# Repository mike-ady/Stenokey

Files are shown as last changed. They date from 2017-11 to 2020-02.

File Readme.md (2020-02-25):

# Stenokey

Stenographic keyboard

Stenokey is an open source do it yourself stenographic keyboard project.  It is aimed 
at makers with some electronics experience (soldering) and who own a 3D printer 
or who have a friend with a 3D printer.

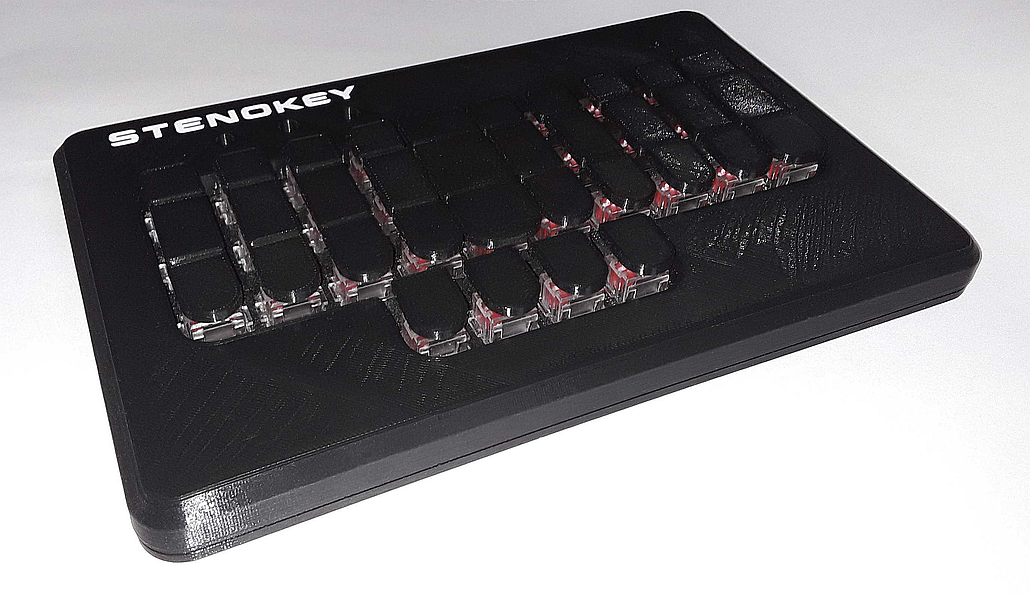
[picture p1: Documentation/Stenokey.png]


Stenokey connects to any desktop or laptop PC that has a USB port.  It is meant 
to work with the Open Steno Project's Plover software, which runs on Linux, Mac and 
Windows.

This project consists of four main parts:

- The OpenSCAD source code for all of the 3D printed plastic parts is in the main 
directory.  Printer ready .STL files for the key tops are in the Key\_Print\_Files 
directory.  The .STL files for the case are in the Case\_Print\_Files directory.  

- The bill of materials (BOM) for populating the circuit board is in the main 
directory.  The PCB design files are in the PCB directory.

- The Arduino based firmware is in the Firmware directory.

- Documentation for the project, including build instructions, programming and testing 
instructions and a user manual are all in the Documentation Directory.

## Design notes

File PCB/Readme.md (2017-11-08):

# Stenokey PCB Readme

Copyright © 2017, Mike Ady  
This file is part of the open source Stenokey project.  
This file is licensed under the Creative Commons Attribution-ShareAlike license.

## Directory Listing

- Gerbers -- This directory holds the files that are required to have circuit boards made.

- Stenokey.pretty -- This directory is the footprint library for the Stenokey project.

- Stenokey.kicad_pcb -- This is the circuit board layout file.

- Stenokey.kicad_wks -- This is the title block and frame layout file.

- Stenokey.lib -- This is the schematic library for the Stenokey project.

- Stenokey.pro -- This is the KiCAD project file.

- StenoKey.sch -- This is the schematic file.

- StenoKeyLogo.kicad_wks -- This is the Stenokey logo in KiCAD format.

The remaining files and directories were program generated.

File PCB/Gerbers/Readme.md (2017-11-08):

# Stenokey Gerbers Readme

Copyright © 2017, Mike Ady  
This file is part of the open source Stenokey project.  
This file is licensed under the Creative Commons Attribution-ShareAlike license.

## Directory Listing

Back.gvp -- This is a Gerbv project file which displays the back of the Stenokey PCB.

Front.gvp -- This is a Gerbv project file which displays the front of the Stenokey PCB.

names.bat -- Windows batch file to rename Gerber files output by KiCAD for submission to SeeedStudio.

StenoKey.GBL -- Bottom copper layer Gerber.

StenoKey.GBO -- Bottom silkscreen layer Gerber.

StenoKey.GBS -- Bottom solder mask layer Gerber.

StenoKey.GML -- Board outline layer Gerber.

StenoKey.GTL -- Top copper layer Gerber.

StenoKey.GTO -- Top silkscreen layer Gerber.

StenoKey.GTS -- Top solder mask layer Gerber.

StenoKey.TXT -- Drill file.

StenoKey.zip -- Archive submitted to SeeedStudio.

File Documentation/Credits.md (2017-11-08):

# Credits

Copyright © 2017, Mike Ady  
This file is part of the open source Stenokey project.  
This file is licensed under the Creative Commons Attribution-ShareAlike license.

# 3D Models

- KMR2 switch model was downloaded from CKSwitches.com.  
- M3 screw model was downloaded from TracePartsOnline.com.  
- Matias key switch model was downloaded from Matias.ca.  
- USB Mini-B model was downloaded from TracePartsOnline.com.  

These models were used generate a full 3D model of the Stenokey to aid in the design of the Stenokey case.

# Fonts (not included)

- Criovision font, by Criovision Agency was downloaded from dafont.com.  The Criovision font was used for the Stenokey logo.

# Tools (not included)

- Arduino IDE -- Arduino programming environment (open source).  The Arduino IDE is used to program the Teensy 2.0.  It was also used to edit and test the Stenokey firmware.  
- DraftSight -- 2D drafting program (free).  DraftSight was used to draw the key and case outlines for use in OpenSCAD.   
- FreeCAD -- 3D drawing program (open source).  FreeCAD was used to view and troubleshoot several .STL files and some of the Stenokey OpenSCAD code.  It was also used to convert files in other 3D formats to .STL format for use with OpenSCAD.  
- FreeRouting -- PCB Auto-routing program (open source).  FreeRouting was used to route the Stenokey PCB.
- Gerbv -- Gerber viewer (open source).  Gerbv (not Gerbview) was used view and verify the Stenokey PCB design.  
- Git -- Revision control system (open source).  Git provides version control.  
- Inkscape -- 2D graphic design program (open source).  Inkscape was used to draw the Stenokey logo.  
- KiCAD -- printed circuit board design software (open source).  KiCAD was used to design the Stenokey PCB.  
- MarkDownPad -- markdown editor and viewer (free -- Windows only).  MarkdownPad was used to format many of the Stenokey documents.  
- Netfabb -- 3D printer design software (free version).  Netfabb was used to obtain measurements from .STL files and to fix errors in .STL files.  
- Plover -- Stenographic translation program (open source).  Plover was used to troubleshoot the Stenokey firmware.  
- OpenOffice -- office utilities (open source).  Open office Calc was used for the Stenokey bill of materials (BOM). 
- OpenSCAD -- 3D drawing program (open source).  OpenSCAD was used to draw all of the Stenokey 3D printed parts.  
- SVG2MOD -- graphic conversion program for KiCAD (open source).  SVG2MOD was used to convert the Stenokey logo from SVG format to a KiCAD module (footprint).  The KiCAD module was hand edited to convert it to .kicad_wks format. 
- TeensyDuino -- Arduino compatible library and utilities (free).  The TeensyDuino libraries are used in the Stenokey firmware.  The Teensy utility is used to program the Teensy 2.0 module.  

# Documents (not included)

- Stenosaurus Keyboard Design was downloaded from stenosaurus.blogspot.ca.  The Stenokey key shapes and general board layout were essentially copied from the Stenosaurus project.
- Matais key switch prints were downloaded from matias.ca.  The prints were used to obtain key switch dimensions.

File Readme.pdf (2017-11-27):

# Stenokey

Stenographic keyboard

Stenokey is an open source do it yourself stenographic keyboard project. It is aimed at makers with some electronics experience (soldering) and who own a 3D printer or who have a friend with a 3D printer.

This project is not quite ready yet! The key tops and circuit board have been tested and are working. Here is a picture of the prototype:

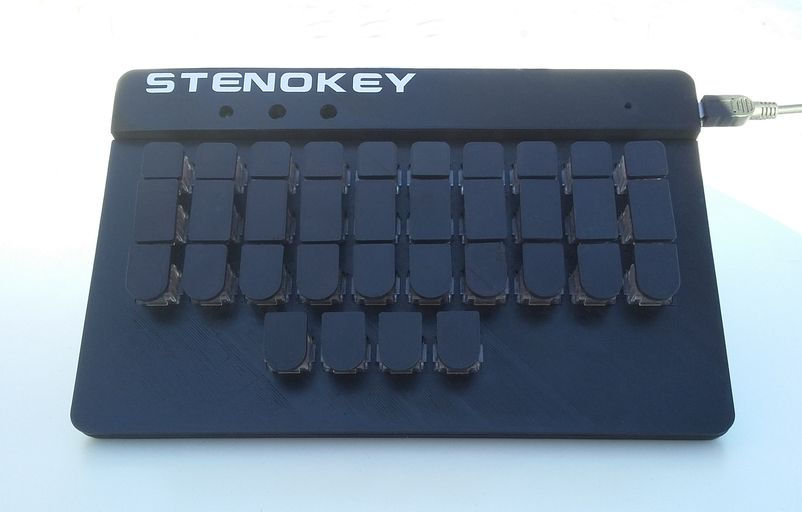
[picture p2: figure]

A clam shell case has been designed but it has not been printed or tested yet:

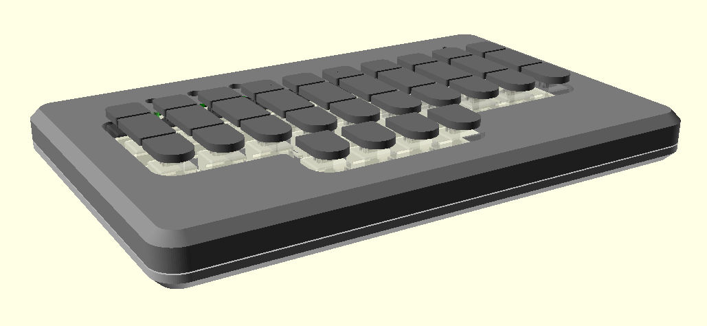
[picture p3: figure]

Stenokey connects to any desktop or laptop PC that has a USB port. It is meant to work with the Open Steno Project's Plover software, which runs on Linux, Mac and Windows.

This project consists of four main parts:

The OpenSCAD source code for all of the 3D printed plastic parts is in the main directory. Printer ready .STL files for the key tops are in the Key_Print_Files directory. The .STL files for the case are in the Case_Print_Files directory.

The bill of materials (BOM) for populating the circuit board is in the main directory. The PCB design files are in the PCB directory.

The Arduino based firmware is in the Firmware directory.

Documentation for the project, including build instructions, programming and testing instructions and a user manual are all in the Documentation Directory.

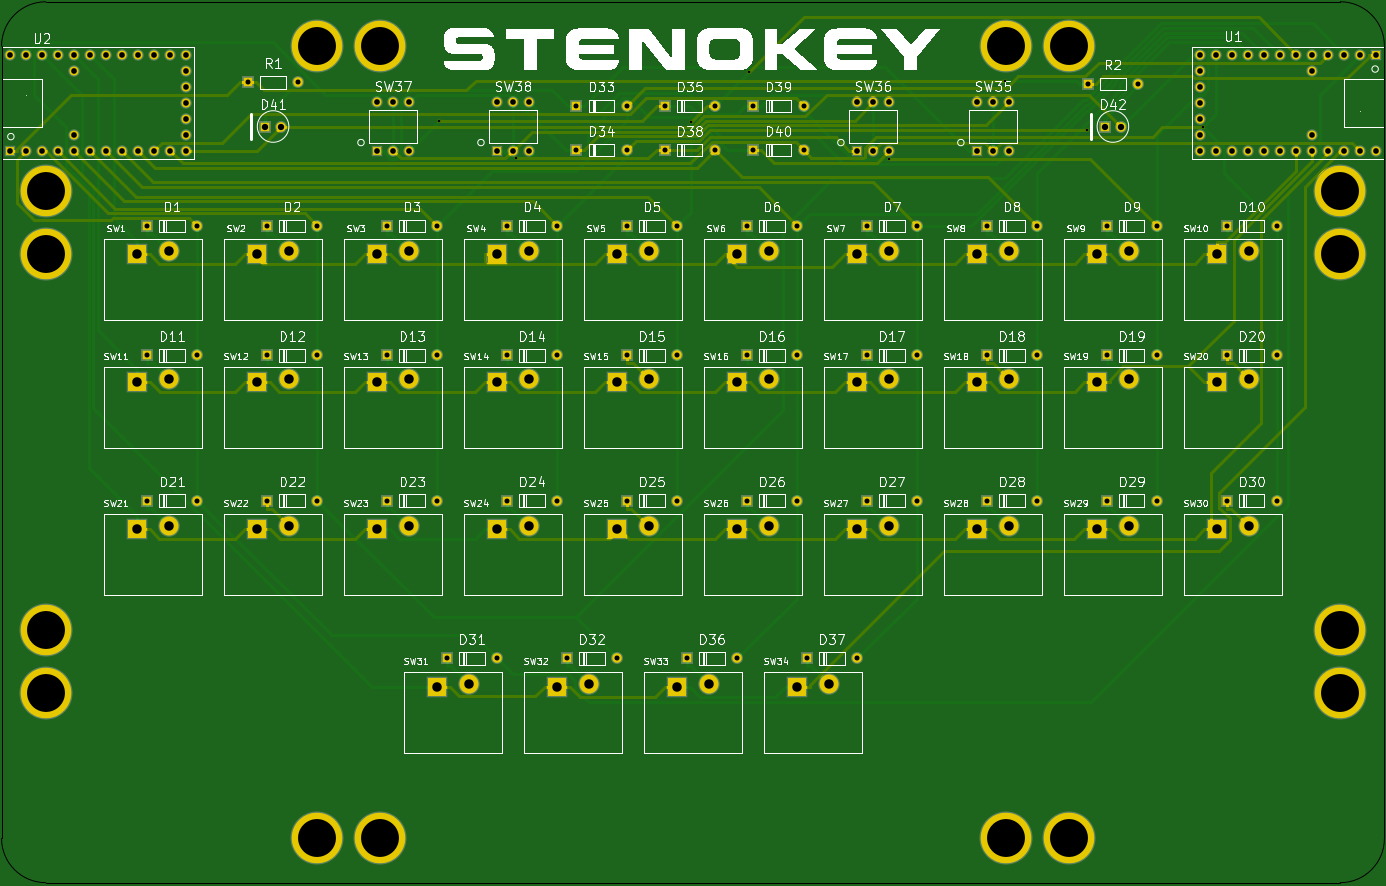
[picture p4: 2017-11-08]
Documentation/PCB_Front.png

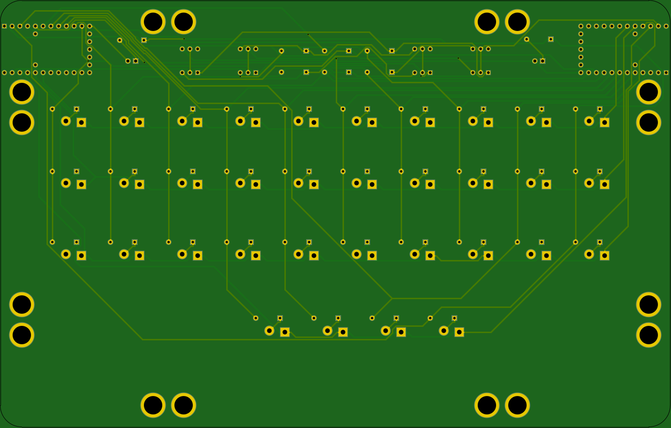
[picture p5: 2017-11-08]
Documentation/PCB_Back.png

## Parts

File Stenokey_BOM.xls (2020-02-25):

Stenokey Bill of Materials |  |  |  |  |  | Price | Price
 |  |  |  |  |  | Break | Break
Ref | Qty | Part Number | Manufacturer | Vendor Part Number | Vendor | Price | Qty | Extended Price | Description | Alternate Vendors
D1-D40 | 40 | 1N4148-T | Rectron | 583-1N4148-T | Mouser | $0.50 | 25 | $0.80 | Small Signal Diode | Digikey, Allied Electronics
D41 | 1 | LTL-307GLC | Liteon | 859-LTL-307GLC | Mouser | $0.10 | 1 | $0.10 | LED, 5 mm Dome, Green, 3 mcd | Digikey, Arrow Electronics
R1 | 1 | 299-510-RC | Xicon | 299-510-RC | Mouser | $0.15 | 10 | $0.01 | Resistor, 510R W125 | Digikey
SW1-SW34 | 34 |  | Matias |  | Matias | $50.00 | 200 | $8.50 | Key Switches, Quiet-Linear | Open Steno Project (Crowd Supply)
SW35-SW36 | 2 | 220ADA16 | CTS | 774-220ADA16 | Mouser | $1.98 | 1 | $3.96 | Rotary Switch, 16 Pos, DIP | Digikey, Arrow Electronics
U1 | 1 | Teensy 2.0 | PJRC | 199 | Adafruit | $15.95 | 1 | $15.95 | Teensy 2.0, with Header Pins | Mouser
 | 1 | N/A | Seeed Studio | N/A | Seeed Studio | $63.15 | 5 | $12.63 | Circuit Board, 1.6 mm | Itead, Osh Park
 | 1 | 88732-8610 | Molex | 538-88732-8610 | Mouser | $2.65 | 1 | $2.65 | Mini B to A USB Cable, 1 m | Digikey
 | 8 | N/A | N/A | 94180A333 | McMaster-Carr | $15.38 | 100 | $1.23 | M3 Heat Set Inserts, Tapered, Long | MakerTech Store
 | 8 | N/A | N/A | 92005A122 | McMaster-Carr | $2.72 | 100 | $0.22 | M3x12 mm Pan Head Screw | Most Hardware Stores
 |  |  |  |  |  | Total |  | $46.05
Component Substitution:
- Small signal diodes -- These are also available from various other manufacturers. Any 1N4148-T diode can be substituted.
- LED -- Note the specified brightness; many LED's are far too bright.
- 510 ohm, 1/8 watt resistor -- This is also available from varous other manufacturers.
- A resistor valued 470 ohms or higher can be substituted, though higher values will reduce the brightness of the LED.
- A 1/4 watt resistor can be substituted, though it's a tight fit.
Copyright © 2017, Mike Ady
This file is part of the open source Stenokey project.
This file is licensed under the GNU GPL V3.0.

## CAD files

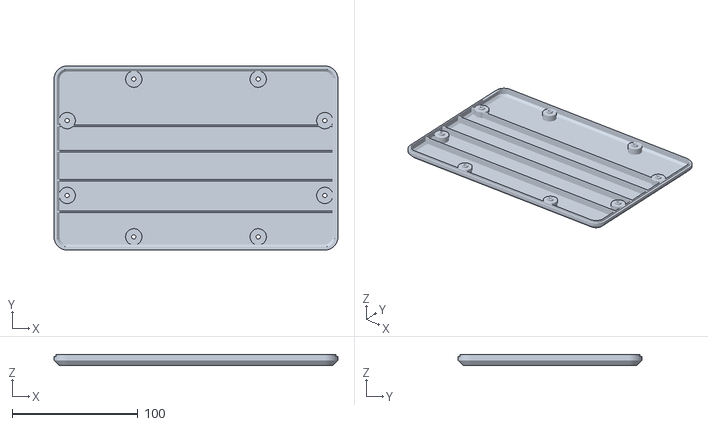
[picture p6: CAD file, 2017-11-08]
Case_Print_Files/BaseUSBLeft.stl
226.0 x 146.5 x 8.60

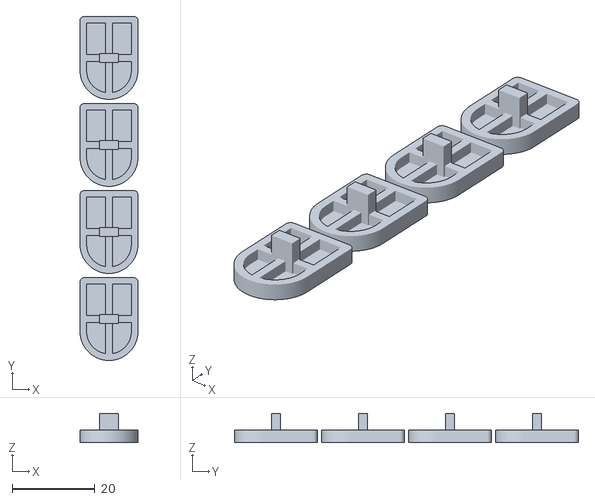
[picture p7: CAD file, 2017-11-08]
Key_Print_Files/Vowels.stl
14.0 x 83.0 x 7.00

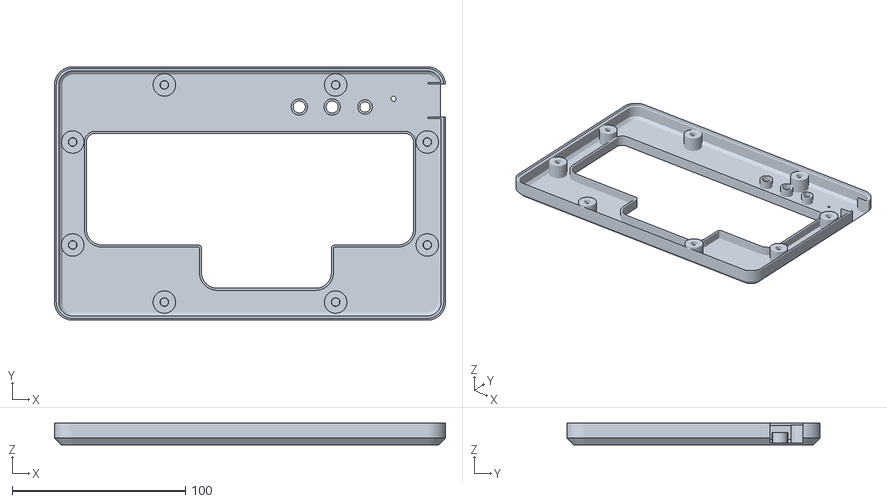
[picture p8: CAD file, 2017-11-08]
Case_Print_Files/TopIntLeftUSBLeft.stl
226.0 x 146.5 x 12.7

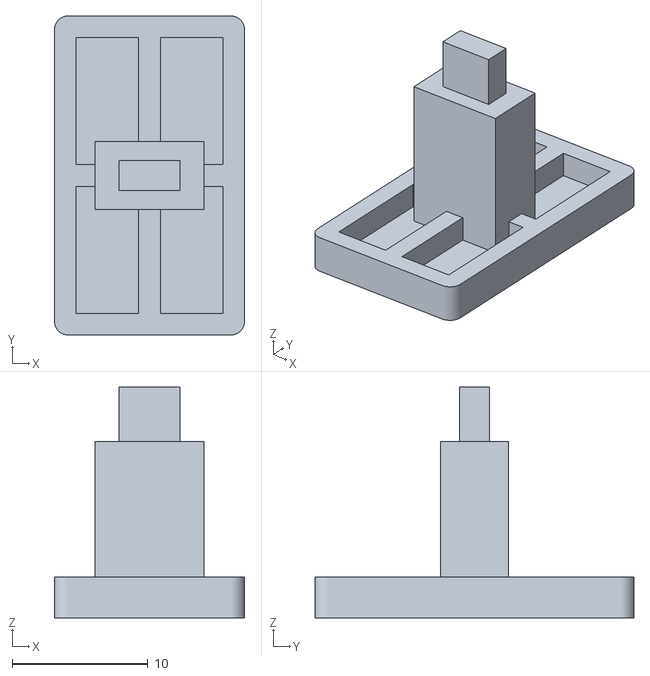
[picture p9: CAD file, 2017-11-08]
Key_Print_Files/KeyMiddleNarrowExtended.stl
14.0 x 23.5 x 17.0

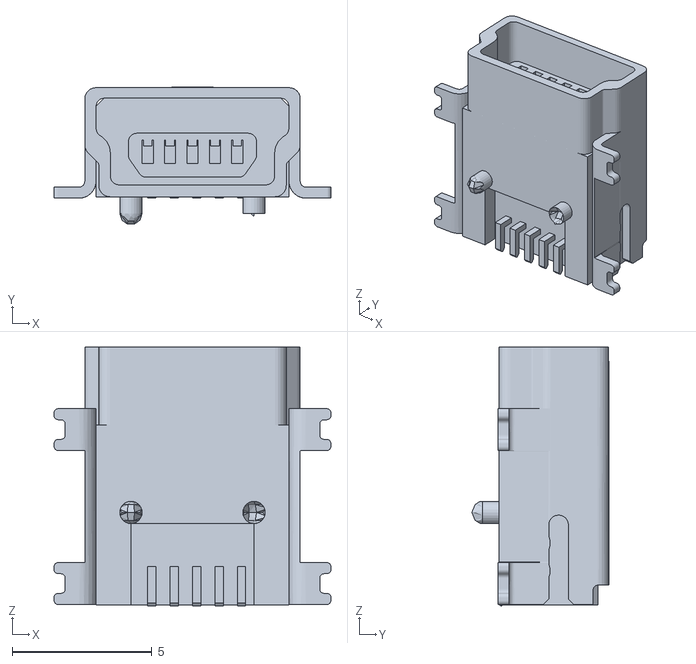
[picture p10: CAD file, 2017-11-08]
USB_MiniB.stl
9.90 x 4.91 x 9.25

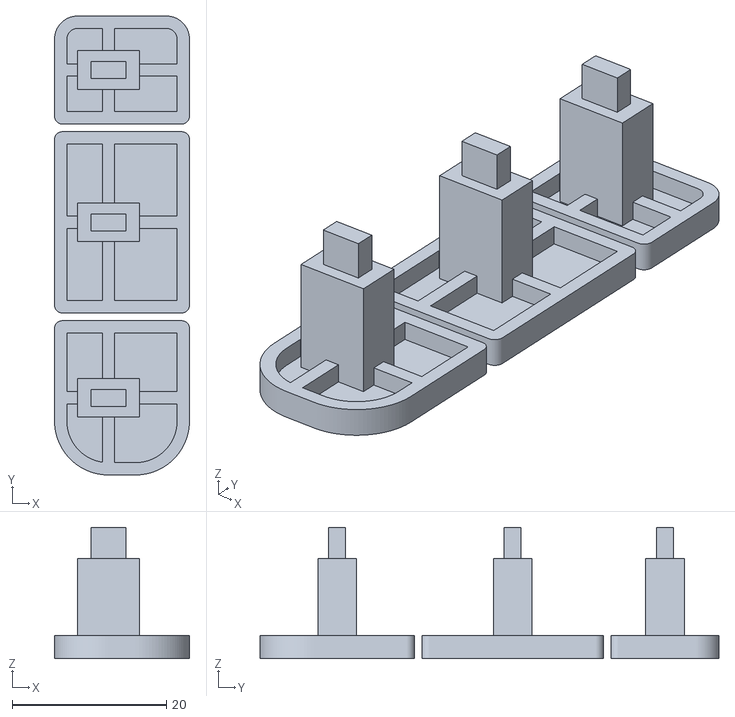
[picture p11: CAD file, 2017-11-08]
Key_Print_Files/FingerWideLeftExtended.stl
17.5 x 59.5 x 17.0

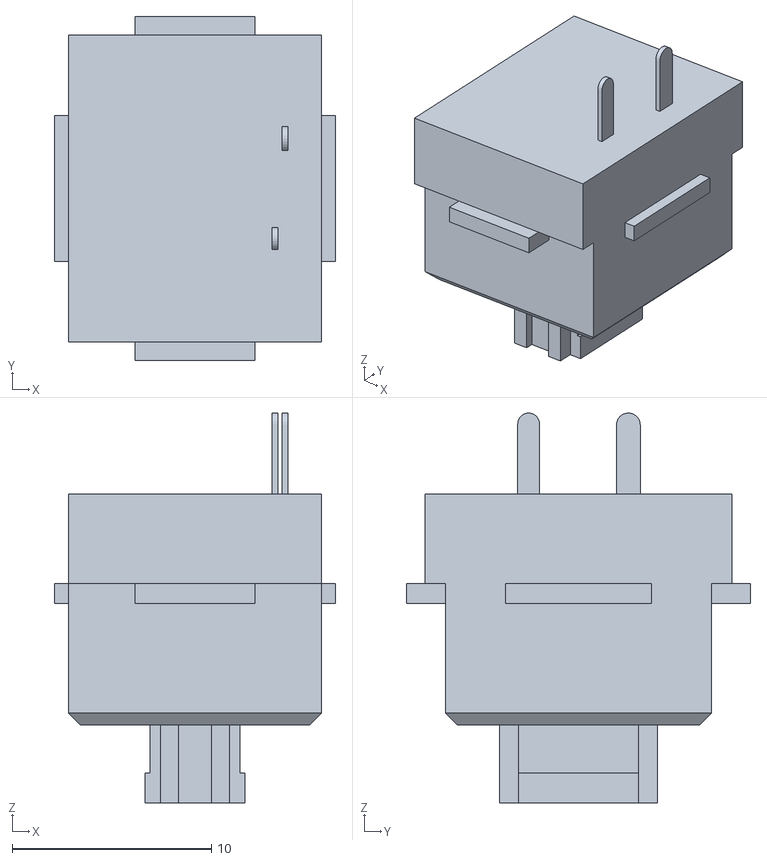
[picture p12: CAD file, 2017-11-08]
Matias_Switch.stl
14.1 x 17.2 x 19.5

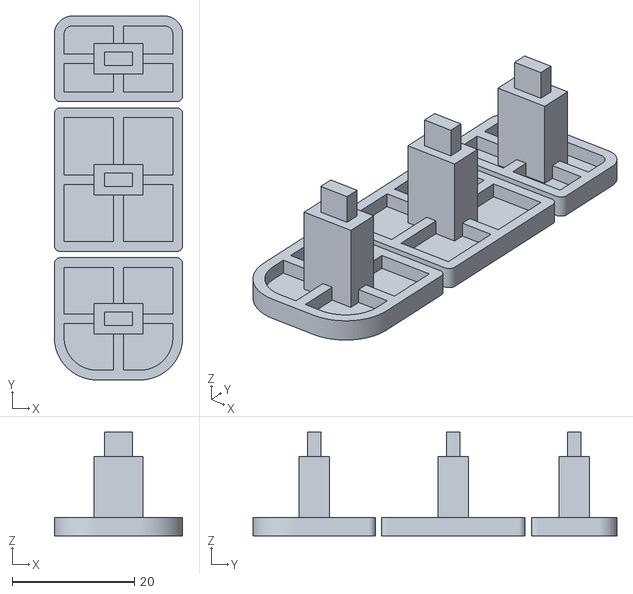
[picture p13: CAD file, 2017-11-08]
Key_Print_Files/FingerDoubleExtended.stl
21.0 x 59.5 x 17.0

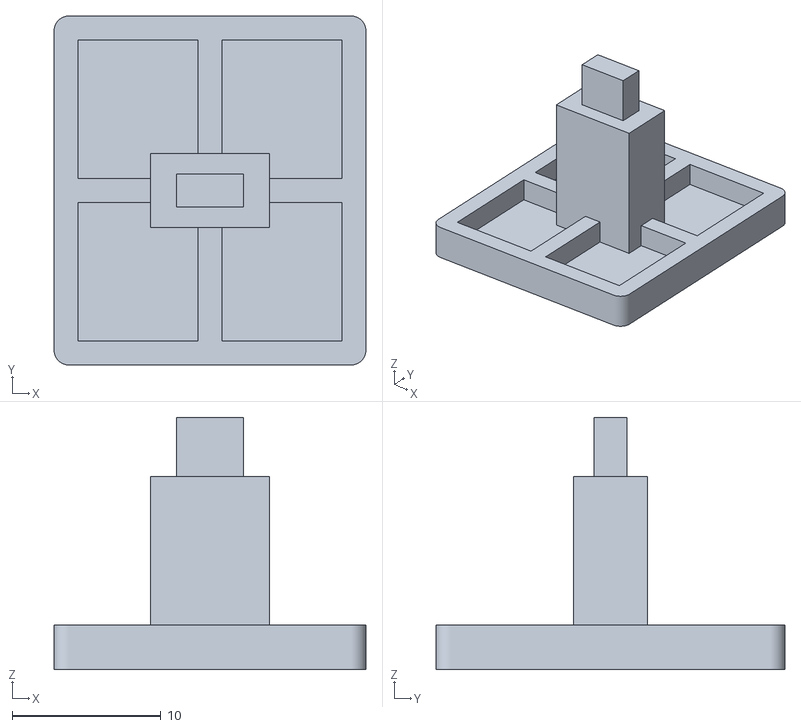
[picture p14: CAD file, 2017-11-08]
Key_Print_Files/KeyMiddleDoubleExtended.stl
21.0 x 23.5 x 17.0

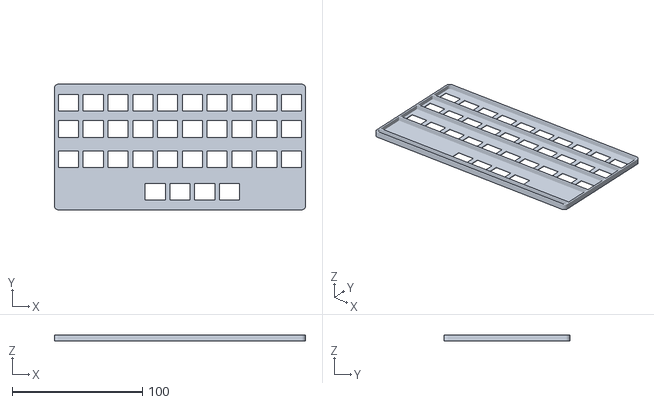
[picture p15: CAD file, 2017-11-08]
Case_Print_Files/KeyMatrix.stl
192.6 x 96.5 x 4.50

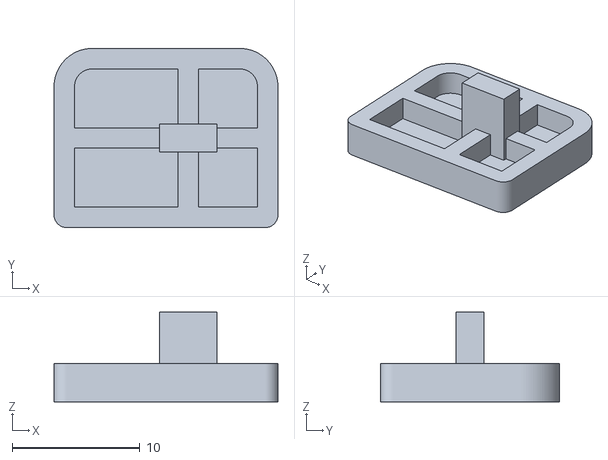
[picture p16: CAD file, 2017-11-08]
Key_Print_Files/KeyUpperWideRight.stl
17.5 x 14.0 x 7.00

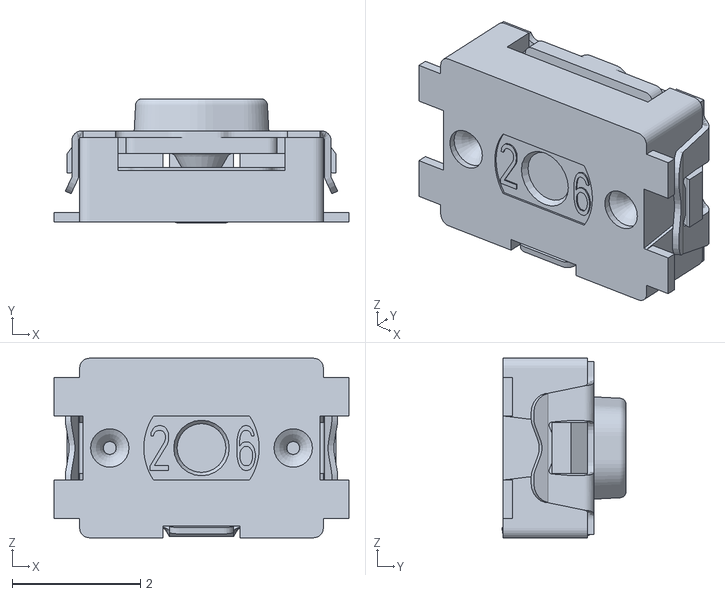
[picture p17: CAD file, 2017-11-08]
KMR2.stl
4.60 x 1.94 x 2.80

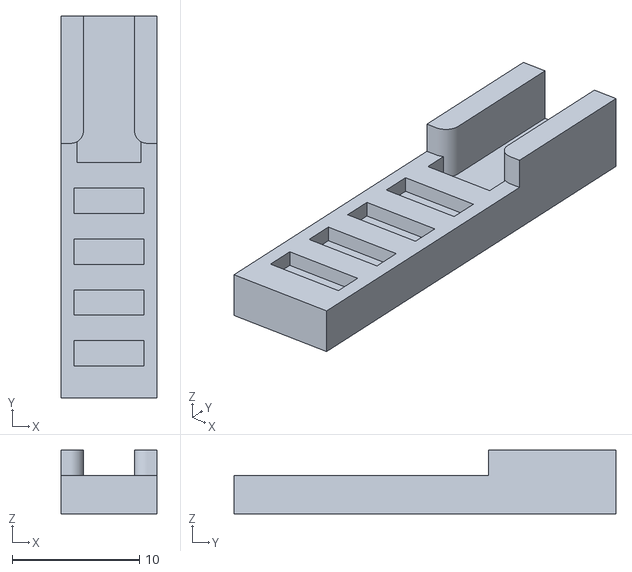
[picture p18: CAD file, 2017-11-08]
Case_Print_Files/LeadBender.stl
7.50 x 30.0 x 5.00

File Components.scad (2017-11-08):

// Components.scad -- various components for Stenokey

// Copyright © 2017, Mike Ady
// This file is part of the open source Stenokey project.
// This file is licensed under the Creative Commons Attribution-ShareAlike license.

// Credits:
//		The Wire module is based on a posting by Hypher  Feb 19, 2015;
//	3:42pm to forum.openscad.org.
//		The MaleHeader and Wire modules are a rework of Guv's "Pin 
//	Headers for OpenSCAD", published as Thingiverse thing:26474.
//	License:  Creative Commons Attribution-ShareAlike

$fn=100;						// nice arcs

DiodeDiameter=2.0;
DiodeLength=4.2;



// Insert -- Draw an M3 heat set insert (McMaster-Carr 94180A333)

module Insert()
{
	color("Goldenrod")
	{
		difference()
		{
			cylinder(d1=5.6,d2=4.8,h=6.4);	// upside down
			translate([0,0,-0.5])
				cylinder(d=3,h=8);
		}
	}
}


// LED -- Draw a 5 mm dome LED

module LED()
{
	LEDHeight=9.6;				// dimensions for LITEON LTL-307GLC
	LEDDiameter=5.0;
	LEDLipDiameter=5.85;
	LEDLipHeight=1.0;
	LEDLipOffset=1.0;
	LEDIndentRadius=1.5;
	LEDLeadLength=3.0;

	union()
	{
		color("LimeGreen",0.7)
		{
			translate([0,0,LEDHeight-LEDDiameter/2])
				sphere(d=LEDDiameter);
			cylinder(d=LEDDiameter,h=LEDHeight-LEDDiameter/2);
			difference()
			{
				hull()
				{
					translate([0,0,LEDLipOffset])
						cylinder(d=LEDLipDiameter,h=LEDLipHeight);
					cylinder(d=LEDDiameter,h=LEDLipOffset);
				}
				translate([-(LEDDiameter/2+LEDIndentRadius),0,-0.5])
					cylinder(r=LEDIndentRadius,h=LEDLipHeight+LEDLipOffset+1);
			}
		}
		color("Silver")
		{
			translate([1.27,0,0])
				cube([0.5,0.5,2*LEDLeadLength],center=true);
			translate([-1.27,0,0])
				cube([0.5,0.5,2*LEDLeadLength],center=true);
		}
	}
}


// RotarySwitch -- Draw a CTS 2200 series rotary switch

//RotarySwitch();

module RotarySwitch()
{
	union()
	{
		difference()
		{
			translate([0,0,3.7/2])
				cube([7.2,7.2,3.7], center=true);
			translate([0,0,3.7-1.0/2+1/2])
				cube([0.7,2.7,1.0+1], center=true);
			translate([0,0,3.5])
				difference()
				{
					cylinder(d=4.0,h=1.0);
					translate([0,0,-0.5])
						cylinder(d=3.5,h=2.0);
				}
		}
		for(row=[-1:2:1],col=[-1:1:1])
		{
			translate([col*2.54-0.25,row*7.62/2,-3.5])
				cube([0.5,0.15,4.5]);
			translate([col*2.54-0.5,row*7.62/2,0])
				cube([1.0,0.15,1.0]);
		}
	}		
}


// Axial -- Draw an axial resistor, diode, capacitor, etc.

module Axial
(
	BodyDiameter,				// body diameter
	BodyLength,					// body length
	WireDiameter,				// wire diameter
	Distance,					// distance between mounting holes 
	BendRadius,					// wire bend radius
	Depth,						// wire depth below cylinder body
	Color						// color of the cylinder body
)
{
	translate([0,0,BodyDiameter/2])
	{
		color(Color)
			rotate([0,90,0])
				cylinder(d=BodyDiameter,h=BodyLength,center=true);
		color("Silver")
		{
			translate([-Distance/2,0,0])
				rotate([180,0,0])
					Wire(r=BendRadius,d=WireDiameter,x=Distance/2,z=Depth+BodyDiameter/2.0);
			translate([Distance/2,0,0])
				rotate([180,0,180])
					Wire(r=BendRadius,d=WireDiameter,x=Distance/2,z=Depth+BodyDiameter/2.0);
		}
	}
}

// Wire -- Draw a wire with a 90 degree bend in the X-Z plane

module Wire
(
	r=2,					// bend radius
	d=1,					// wire diameter
	x=10,					// length along y axis
	z=10					// length along z axis
)
{
	detail=$fn;

	translate([0,0,r]) // vertical part
		cylinder(r=d/2, h=z-r, $fn=detail);
	translate([r,0,0])
		rotate([0,90,0])
			cylinder(r=d/2, h=x-r, $fn=detail);
    translate([0,0,r])
		rotate([90,0,0])
			translate([r,0,0])
				difference()
				{
					rotate_extrude($fn=60,convexity=4)
						translate([r,0])
							rotate([0,0,360/detail/2])
								circle(d/2,$fn=detail);
					translate([0,2*r,0])
						cube(4*r,true);
					translate([2*r,0,0])
						cube(4*r,true);
				}
}

// Teensy2_0 -- Draw a Teensy 2.0 board

//Teensy2_0();
//translate([0,7.62,-5.5])
//	MaleHeader(length=8.5, upper=3.0, rows=1, cols=12);
//translate([0,-7.62,-5.5])
//	MaleHeader(length=8.5, upper=3.0, rows=1, cols=12);


module Teensy2_0()
{
	TeensyWidth=17.78;
	TeensyLength=30.48;
	TeensyDepth=1.6;
	TeensyPitch=2.54;
	TeensyHoleDiameter=0.9;
	TeensyButtonPosX=11.0;
	TeensyButtonPosY=0.7;
	TeensyUSBPosX=-TeensyLength/2.0-0.5;
	TeensyUSBPosY=0.0;
	
	union()
	{
		difference()
		{
			color("DarkGreen")
				translate([-TeensyLength/2.0,-TeensyWidth/2.0,0])
					cube([TeensyLength,TeensyWidth,TeensyDepth]);
			color("Silver")
			{
				for(i=[0:11])
				{
					translate([i*TeensyPitch-(TeensyLength-TeensyPitch)/2.0,3*TeensyPitch,-0.5])
						cylinder(d=TeensyHoleDiameter,h=TeensyDepth+1.0);
					translate([i*TeensyPitch-(TeensyLength-TeensyPitch)/2.0,-3*TeensyPitch,-0.5])
						cylinder(d=TeensyHoleDiameter,h=TeensyDepth+1.0);
				}
				for(i=[0:4])
				{
					translate([(TeensyLength-TeensyPitch)/2.0,i*TeensyPitch-(TeensyWidth-3*TeensyPitch)/2.0,-0.5])
						cylinder(d=TeensyHoleDiameter,h=TeensyDepth+1.0);
				}
				for(i=[0:1])
				{
					translate([(9*TeensyPitch-TeensyLength)/2.0,i*TeensyPitch*4-(TeensyWidth-3*TeensyPitch)/2.0,-0.5])
						cylinder(d=TeensyHoleDiameter,h=TeensyDepth+1.0);
				}
			}		
		}
		color("Silver")
		{
			translate([TeensyUSBPosX,TeensyUSBPosY,TeensyDepth])
				rotate([90,0,-90])
					import("USB_MiniB.stl");
			translate([TeensyButtonPosX,TeensyButtonPosY,TeensyDepth])
				rotate([90,0,-90])
					import("KMR2.stl");
		}
	}
}

// MaleHeader -- Draw a Row of Male Header Pins

// Header dimensions vary widely from manufacturer to manufacturer.
// The default dimensions were taken from some headers that I had lying around.

Pitch=2.54;				// distance between pins (e.g. center to center)
PinWidth=0.64;			// pin width
RetainerHeight=2.5;		// height of insulating pin retainer

// example

//MaleHeader(length=8.5,upper=3.0,rows=3,cols=2);

module MaleHeader
(
	length=11.4,		// total length of the pin
	upper=5.9,			// length of the pin above the retainer
	rows=12,			// number of rows
	cols=1				// number of columns
)
{
	union()
	{
		// generate the retainer
		
		color("dimgray")
		{
			translate([0,0,length-upper-RetainerHeight/2])
			{
				intersection()
				{
					for(row=[0:rows-1],col=[0:cols-1])
					{
						translate([-(cols-1)*Pitch/2+Pitch*col,-(rows-1)*Pitch/2+Pitch*row,0])
						{
							rotate([0,0,45])
								cube([Pitch*1.1,Pitch*1.1,RetainerHeight],center=true);
						}
					}
					cube([cols*Pitch,rows*Pitch,RetainerHeight],center=true);
				}
			}
		}
		
		// generate the pins
		
		color("silver")
		{
			for(row=[0:rows-1],col=[0:cols-1])
			{
				translate([-(cols-1)*Pitch/2+Pitch*col,-(rows-1)*Pitch/2+Pitch*row,0])
					Pin(length=length);
			}
		}
	}
}

// Pin -- Draw a Single Male Header Pin

// most real pins have square tips (pyramidal frustra)
// these ones have simple pyramids at their tips

module Pin
(
	width=0.64,				// pin width
	length=11.4				// pin length
)
{
	Points=[
		[0,0,0],
		[-0.5*width,-0.5*width,0.5*width],
		[-0.5*width,0.5*width,0.5*width],
		[0.5*width,0.5*width,0.5*width],
		[0.5*width,-0.5*width,0.5*width],
		[-0.5*width,-0.5*width,length-0.5*width],
		[-0.5*width,0.5*width,length-0.5*width],
		[0.5*width,0.5*width,length-0.5*width],
		[0.5*width,-0.5*width,length-0.5*width],
		[0,0,length]];
	Faces=[					// orient all faces counter clockwise
		[0,2,1],[0,3,2],[0,4,3],[0,1,4],
		[1,2,6,5],[2,3,7,6],[3,4,8,7],[4,1,5,8],
		[5,6,9],[6,7,9],[7,8,9],[8,5,9]
	];
	polyhedron(points=Points,faces=Faces);
}

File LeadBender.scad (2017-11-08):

// LeadBender.scad -- Lead bender jig for 1/8 watt resistors and small signal diodes

// Copyright © 2017, Mike Ady
// This file is part of the open source Stenokey project.
// This file is licensed under the Creative Commons Attribution-ShareAlike license.

$fn=100;					// nice arcs

color("Silver")
	LeadBender();

module LeadBender()
{
	difference()
	{
		union()
		{
			// bending post

			translate([0.75,1,0])
				cylinder(r=1.0,h=5.0);
			translate([-0.25,0,0])
				cube([1,10,5]);
			translate([-0.25,1,0])
				cube([2,9,5]);

			// bending post
	
			translate([6.75,1,0])
				cylinder(r=1.0,h=5.0);
			translate([6.75,0,0])
				cube([1,10,5]);
			translate([5.75,1,0])
				cube([2,9,5]);

			difference()
			{
				// back plate

				translate([-0.5,-20,0])
					cube([8.5,30,3]);

				// recess for component
	
				translate([1.25,-1.5,1.5])
					cube([5.0,12,2]);
			}
		}
	
		// recesses for thumb grip

		for(i=[0:3])
		{
			translate([1.0,-5.5-4*i,2.0])
				cube([5.5,2,2]);
		}

		// shave off sides

		translate([-1.0,-20.5,-0.5])
			cube([1,31,6]);
		translate([7.5,-20.5,-0.5])
			cube([1,31,6]);
	}
}

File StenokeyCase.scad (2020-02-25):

// StenokeyCase.scad -- keyboard case

// Copyright © 2017, Mike Ady
// This file is part of the open source Stenokey project.
// This file is licensed under the Creative Commons Attribution-ShareAlike license.

// The Stenokey keys and case are based on designs by Joshua Lifton.

include <StenokeyKeys.scad>
include <Components.scad>

$fn=100;						// nice arcs

PCBDimX=219.0;
PCBDimY=139.5;
PCBDimZ=1.6;
CaseExtra=3.5;					// extra X and Y dimensions of case on each side of PCB
DimX=PCBDimX+2.0*CaseExtra;		// outside dimension
KeyMatrixDimX=219.0;			// outside dimension
KeyMatrixDimY=111.9;			// outside dimension
KeyMatrixDimZ=4.5;				// 4.5 nominal per Matias prints
BaseDimZ=7.0;					// outside dimension
KeySwitchHeight=11.6;			// 11.6 nominal per Matias prints
TopDimZ=KeySwitchHeight+PCBDimZ;	// outside dimension

LipThickness=2.5;				// case lip thickness

CutoutX=15.5;					// 15.5 nominal per Matias prints
CutoutY=12.8;					// 12.8 nominal per Matias prints

SpacingX=19.0;					// distance from left edge of one cutout to left edge of next

VowelX0=82.75;					// offset from outside right edge to cutout right edge (backwards!)
VowelY0=20.6;					// offset from outside bottom edge to cutout bottom edge

ConsonantX0=16.25;				// offset from outside right edge to cutout right edge (backwards!)
ConsonantY0=45.6;				// offset from outside bottom edge to cutout bottom edge
ConsonantY1=68.85;				// offset from outside bottom edge to cutout bottom edge
ConsonantY2=89.1;				// offset from outside bottom edge to cutout bottom edge

FaceThickness=1.0;				// 1.1 nominal per Matias prints
WallThickness=1.2;
RibThickness=1.2;

//RibOffset=1.0;				// rib offset from bottom edge of cutouts

BaseRibY0=VowelY0+CutoutY/2.0;		// rib midline from bottom outside edge
BaseRibY1=ConsonantY0+CutoutY/2.0;	// rib midline from bottom outside edge
BaseRibY2=ConsonantY1+CutoutY/2.0;	// rib midline from bottom outside edge
BaseRibY3=ConsonantY2+CutoutY/2.0;	// rib midline from bottom outside edge

File="StenokeyCase.dxf";		// file path for layout drawings
LeftOpeningLayer="LeftOpening";	// layer for top key opening with left interface
RightOpeningLayer="RightOpening";	// layer for key opening with right interface
OutlineLayer="Outline";			// layer for top and base layout
PCBOutlineLayer="PCBOutline";	// layer for PCB layout
PCBLayer="PCB";					// layer for PCB layout
KeyMatrixLayer="Keymatrix";		// layer for key matrix layout

TopV1Layer="TopV1";				// layer for top layout
KeyMatrixV1Layer="KeymatrixV1";	// layer for key matrix layout
LeftOpeningV1Layer="LeftOpeningV1";	// layer for top left interface
RightOpeningV1Layer="RightOpeningV1";	// layer for top right interface


LowerRegisterX=[50.0,169.0,7.0,212.0,7.0,212.0,50.0,169.0];	// for base
LowerRegisterY=[7.0,7.0,40.0,40.0,109.5,109.5,132.5,132.5];
UpperRegisterX=[60.0,159.0,7.0,212.0,7.0,212.0,60.0,159.0];	// for key matrix
UpperRegisterY=[7.0,7.0,30.0,30.0,99.5,99.5,132.5,132.5];

InnerRegisterX=[60.0,159.0,7.0,212.0,7.0,212.0,60.0,159.0];
InnerRegisterY=[7.0,7.0,40.0,40.0,99.5,99.5,132.5,132.5];
OuterRegisterX=[50.0,169.0,7.0,212.0,7.0,212.0,50.0,169.0];
OuterRegisterY=[7.0,7.0,30.0,30.0,109.5,109.5,132.5,132.5];

RegisterPinDiameter=5.8;	// 6.0 plated hole
RegisterBaseDiameter=13.0;
PCBHoleDiameter=6.0;

BaseLipHeight=3.0;
TopLipHeight=7.6+PCBDimZ;

bShowAxial=false;			// show axial components (really slows down screen updates in preview mode)

ScrewDiameter=3.4;			// M3 (nominal 3.0 mm)
ScrewHeadZ=3.0;				// M3 pan head (nominal 2.4 mm)
ScrewHeadDiameter=6.0;		// M3 pan head (max 6 mm)
ScrewRecessDiameter=8.0;	// M3 pan head (max 6 mm)

KeyMatrixOffsetX=13.2;
KeyMatrixOffsetY=13.2;
SwitchElevation=7.1;		// 7.1 nominal per Matias prints (switch height above keymatrix)
SwitchExtension=3.8;		// 3.8 nominal per Matias prints (switch plunger height above switch body)

LeftLEDPosX=43.0;
LeftLEDPosY=119.75;
LeftResistorPosX=43.0;
LeftResistorPosY=126.75;
LeftProtocolSwitchPosX=62.0;
LeftProtocolSwitchPosY=119.75;
LeftBrightnessSwitchPosX=81.0;
LeftBrightnessSwitchPosY=119.75;

RightLEDPosX=176.0;
RightLEDPosY=119.75;
RightResistorPosX=176.0;
RightResistorPosY=126.75;
RightProtocolSwitchPosX=157.0;
RightProtocolSwitchPosY=119.75;
RightBrightnessSwitchPosX=138.0;
RightBrightnessSwitchPosY=119.75;

LeftResistorLeadX=47.0;
LeftResistorLeadY=126.75;
RightResistorLeadX=172.0;
RightResistorLeadY=126.5;

DiodeOffsetX=3.0;				// diode position with respect to key switch
DiodeOffsetY=8.5;

LeftTeensyPosX=15.25;
RightTeensyPosX=203.75;
TeensyPosY=123.5;

LeftResetHolePosX=192.5;		// right and left are reversed on top!
LeftResetHolePosY=124.5;
RightResetHolePosX=26.5;
RightResetHolePosY=122.5;
ResetHoleDiameter=3.0;

D33PosX=95.0;					// rotary switch decoding diodes
D33PosY=123.0;
D34PosX=95.0;
D34PosY=116.0;
D35PosX=109.0;
D35PosY=123.0;

D38PosX=109.0;
D38PosY=116.0;
D39PosX=123.0;
D39PosY=123.0;
D40PosX=123.0;
D40PosY=116.0;

InsertHeight=6.4;
InsertD1=4.7;
InsertD2=6.0;

// Generate models -----------------------------------

bInterfaceLeft=true;		// put LED and rotary switches on the left
bTeensyLeft=false;			// put Teensy on the left

//Top();
//KeyMatrix();
//Base();
StenoKey();

//TopV1();
//KeyMatrixV1();
//BaseV1();
//StenoKeyV1();

// StenoKey -- draw the assembly of all parts

module StenoKey()
{

	// generate the top

	color("gray")
		translate([DimX,0,TopDimZ+BaseDimZ])
			rotate([0,180,0])
				Top();

	if(bInterfaceLeft)
	{
		// draw the LED
	
		translate([LeftLEDPosX+CaseExtra,LeftLEDPosY+CaseExtra,BaseDimZ+PCBDimZ])
			LED();

		// draw the resistor
	
		if(bShowAxial)
		{
			translate([LeftResistorPosX+CaseExtra,LeftResistorPosY+CaseExtra,BaseDimZ+PCBDimZ])
				Axial(BodyDiameter=1.9,BodyLength=3.9,WireDiameter=0.5,Distance=8.0,BendRadius=0.9,Depth=3.0,Color="PaleGoldenrod");
		}

		// draw the protocol switch

		translate([LeftProtocolSwitchPosX+CaseExtra,LeftProtocolSwitchPosY+CaseExtra,BaseDimZ+PCBDimZ])
			color("Silver")
				RotarySwitch();
		
		// draw the brightness switch

		translate([LeftBrightnessSwitchPosX+CaseExtra,LeftBrightnessSwitchPosY+CaseExtra,BaseDimZ+PCBDimZ])
			color("Silver")
				RotarySwitch();
	}
	else
	{
		// draw the LED

		translate([RightLEDPosX+CaseExtra,RightLEDPosY+CaseExtra,BaseDimZ+PCBDimZ])
			LED();

		// draw the resistor
	
		if(bShowAxial)
		{
			translate([RightResistorPosX+CaseExtra,RightResistorPosY+CaseExtra,BaseDimZ+PCBDimZ])
				Axial(BodyDiameter=1.9,BodyLength=3.9,WireDiameter=0.5,Distance=8.0,BendRadius=0.9,Depth=3.0,Color="PaleGoldenrod");
		}

		// draw the protocol switch

		translate([RightProtocolSwitchPosX+CaseExtra,RightProtocolSwitchPosY+CaseExtra,BaseDimZ+PCBDimZ])
			color("Silver")
				RotarySwitch();
		
		// draw the brightness switch

		translate([RightBrightnessSwitchPosX+CaseExtra,RightBrightnessSwitchPosY+CaseExtra,BaseDimZ+PCBDimZ])
			color("Silver")
				RotarySwitch();
	}

	// draw the teensy
	
	translate([(bTeensyLeft?LeftTeensyPosX:RightTeensyPosX)+CaseExtra,TeensyPosY+CaseExtra,BaseDimZ+PCBDimZ])
	{
		translate([0,7.62,-3.0])
			MaleHeader(length=8.5, upper=3.0, rows=1, cols=12);
		translate([0,-7.62,-3.0])
			MaleHeader(length=8.5, upper=3.0, rows=1, cols=12);
		translate([0,0,2.5])
		{
			if(bTeensyLeft)
			{
//				rotate([0,0,0])
					Teensy2_0();
			}
			else
			{
				rotate([0,0,180])
					Teensy2_0();
			}
		}
	}

	if(bShowAxial)
	{
		// draw the rotary switch diodes

		translate([D33PosX+CaseExtra,D33PosY+CaseExtra,BaseDimZ+PCBDimZ])
			Axial(BodyDiameter=2,BodyLength=4.2,WireDiameter=0.5,Distance=8.0,BendRadius=1.0,Depth=3.0,Color="Gray");
		translate([D34PosX+CaseExtra,D34PosY+CaseExtra,BaseDimZ+PCBDimZ])
			Axial(BodyDiameter=2,BodyLength=4.2,WireDiameter=0.5,Distance=8.0,BendRadius=1.0,Depth=3.0,Color="Gray");
		translate([D35PosX+CaseExtra,D35PosY+CaseExtra,BaseDimZ+PCBDimZ])
			Axial(BodyDiameter=2,BodyLength=4.2,WireDiameter=0.5,Distance=8.0,BendRadius=1.0,Depth=3.0,Color="Gray");

		translate([D38PosX+CaseExtra,D38PosY+CaseExtra,BaseDimZ+PCBDimZ])
			Axial(BodyDiameter=2,BodyLength=4.2,WireDiameter=0.5,Distance=8.0,BendRadius=1.0,Depth=3.0,Color="Gray");
		translate([D39PosX+CaseExtra,D39PosY+CaseExtra,BaseDimZ+PCBDimZ])
			Axial(BodyDiameter=2,BodyLength=4.2,WireDiameter=0.5,Distance=8.0,BendRadius=1.0,Depth=3.0,Color="Gray");
		translate([D40PosX+CaseExtra,D40PosY+CaseExtra,BaseDimZ+PCBDimZ])
			Axial(BodyDiameter=2,BodyLength=4.2,WireDiameter=0.5,Distance=8.0,BendRadius=1.0,Depth=3.0,Color="Gray");
	}

	// place the Matias key switches and the key tops
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

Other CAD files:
StenokeyKeys.dxf
Case_Print_Files/TopIntRightUSBLeft.stl
Case_Print_Files/BaseUSBRight.stl
StenokeyCase.dxf
Case_Print_Files/TopIntLeftUSBRight.stl
StenokeyKeys.scad
Case_Print_Files/TopIntRightUSBRight.stl
Key_Print_Files/FingerDouble.stl
Key_Print_Files/FingerNarrow.stl
Key_Print_Files/FingerNarrowExtended.stl
Key_Print_Files/FingerWideCenter.stl
Key_Print_Files/FingerWideCenterExtended.stl
Key_Print_Files/FingerWideLeft.stl
Key_Print_Files/FingerWideRight.stl
Key_Print_Files/FingerWideRightExtended.stl
Key_Print_Files/KeyLowerDouble.stl
Key_Print_Files/KeyLowerDoubleExtended.stl
Key_Print_Files/KeyLowerNarrow.stl
Key_Print_Files/KeyLowerNarrowExtended.stl
Key_Print_Files/KeyLowerWideCenter.stl
Key_Print_Files/KeyLowerWideCenterExtended.stl
Key_Print_Files/KeyLowerWideLeft.stl
Key_Print_Files/KeyLowerWideLeftExtended.stl
Key_Print_Files/KeyLowerWideRight.stl
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

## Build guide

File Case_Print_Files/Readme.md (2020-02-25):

# Stenokey Case Readme

Copyright © 2017, 2020, Mike Ady  
This file is part of the open source Stenokey project.  
This file is licensed under the Creative Commons Attribution-ShareAlike license.

DO NOT PRINT ALL OF THE FILES IN THIS DIRECTORY!

The Stenokey case consists of a top, a base and a key matrix.  
The case encloses the Stenokey circuit board.  The base is 
affixed to the top by means of 8 M3 machine screws and 8 heat 
set inserts.  The purpose of the key matrix is to support and 
align the key switches.  

The case top is available in 4 variants, which allow for the 
USB cable to be plugged in from the left or the right, and for 
the interface elements (two options switches and a power LED) 
to be placed on the left or the right.  Only one of the 4 case 
top variants need be printed, and the Stenokey circuit board 
must be populated with components to match the particular 
variant that is chosen.  

The case base is available in 2 variants.  The location of the 
interface components has no effect on the shape of the base so 
there are only variants which place the USB cable on the left 
or right.  Only one of the case base variants need be printed,
and it must match the case top variant chosen. 

## Print Instructions

The Stenokey case parts were printed successfully under the 
following conditions:

Nozzle:  0.4 mm  
Layer:  0.2 mm  
Filament:  PLA, modified  
Extruder:  Follow filament manufacturer's temperature recommendation.  
Heated bed: 50° to 60° C  
Interior:  50% infill  
Exterior: 100% infill, 0.8 mm thick (4 layers) top and bottom, 
double shell (0.8 mm)  
No Raft

Allow the bed to cool below the filament's glass temperature before 
removing parts to avoid bending and ruining the parts. 

## Directory Contents

- "BaseUSBLeft.stl" -- This file contains the case base 
variant with the Teensy micro controller (and USB cable) on 
the left.

- "BaseUSBRight.stl" -- This file contains the case base 
variant with the Teensy micro controller (and USB cable) on 
the right.

- "KeyMatrix.stl" -- This file contains the key support matrix.

- "TopIntLeftUSBLeft.stl" -- This file contains the case top 
variant which places both the interface elements and the 
Teensy micro controller (and USB cable) on the left.

- "TopIntRightUSBLeft.stl" -- This file contains the case top 
variant which places the interface elements on the right and 
the Teensy micro controller (and USB cable) on the left.

- "TopIntLeftUSBRight.stl" -- This file contains the case top 
variant which places the interface elements on the left and 
the Teensy micro controller (and USB cable) on the right.

- "TopIntRightUSBRight.stl" -- This file contains the case top 
variant which places both the interface elements and the 
Teensy micro controller (and USB cable) on the right.

- "LeadBender.stl" -- This file contains a simple lead bending 
jig which can be used to quickly bend the leads on the small 
axial components used on the Stenokey circuit board.

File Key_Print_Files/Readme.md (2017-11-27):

# Stenokey Key Tops Readme

Copyright © 2017, Mike Ady  
This file is part of the open source Stenokey project.  
This file is licensed under the Creative Commons Attribution-ShareAlike license.

DO NOT PRINT ALL OF THE FILES IN THIS DIRECTORY!

Avoid printing single keys!  Try to print at least two keys at a time 
to avoid over heating and distortion of the key stems.  Always 
print with the printer's cooling fan enabled above the first layer.

A standard steno keyboard consists of 10 sets of 3 consonant keys 
and a set of 4 vowel keys.  This can be obtained by printing 10 
copies of the files that are named with a "Finger" prefix (in any workable combination) plus the Vowels file.  Note that some 
combinations of wide and double wide keys cannot be fit next to 
each other on the keyboard.  

## Print Instructions

The Stenokey key tops were printed successfully under the 
following conditions:

Nozzle:  0.4 mm  
Layer:  0.2 mm  
Filament:  PLA, modified  
Extruder:  Follow filament manufacturer's temperature recommendation.  
Heated bed: 50° to 60° C  
Interior:  50% infill  
Exterior: 100% infill, 0.8 mm thick (4 layers) top and bottom, 
double shell (0.8 mm)  
No Raft

Allow plenty of room between rows of key tops when printing 
parts without extensions.  It may be almost impossible to 
remove the parts otherwise.  Allow the bed to cool below the 
filament's glass temperature before removing parts to avoid 
bending and ruining them. 
  
Once printed, the keys should fit snugly into the plungers of the 
Matias key switches, so that they don't fall out.  If you have difficulty inserting a key into a key switch, use a fingernail 
file on the key stem to reduce its size.  Usually a couple of 
swipes of a file on each face of the key stem is sufficient.

## Directory Contents

File naming convention:

- "Vowels" -- This file contains 4 narrow vowel keys.

- "Finger" -- All of these files contain 3 consonant keys, upper, 
middle and lower.

- "Key" -- All of these files contain a single key only.

- "Narrow" -- The key or keys in these files are the standard key 
width.

- "Double" -- The key or keys in these files have extra width on 
both the left and the right.

- "WideLeft" -- The key or keys in these files have extra width on 
the left side.

- "WideRight" -- The key or keys in these files have extra width on 
the right side.

- "WideCenter" -- The key or keys in these files have their extra 
width split evenly on the left and the right.

- "Extended" -- The key or keys in these files have extensions on 
their stems, so that they are raised up above the vowel keys.

- "Upper" -- The key in these files is used in the upper consonant 
row on the steno keyboard.

- "Middle" -- The key in these files is used in the middle 
consonant row on the steno keyboard.

- "Lower" -- The key in these files is used in the lower consonant 
row on the steno keyboard.  Any of the lower keys (without 
extensions) can also be used as vowel keys.

The TestStand.stl file is provided to make it easier to check the 
fit of the key stems in a Matias key switch.  You may need to 
scrape the inside edges of the opening in the test stand with a 
sharp knife to fit a key switch into the stand.

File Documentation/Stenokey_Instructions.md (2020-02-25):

# Stenokey Build Instructions

Copyright © 2017, 2020, Mike Ady  
This file is part of the open source Stenokey project.  
This file is licensed under the Creative Commons Attribution-ShareAlike license.

**Warning:**  Please follow all instructions in order.  It may be almost impossible to recover if you attempt to put things together in the wrong order.  

Once the plastic parts have been printed, you should be able to build the Stenokey in an afternoon or an evening.  However, take your time.  If you get tired or worse, cranky, set things aside and complete the project at another time when your outlook is better.

1.  Bill of materials (see Stenokey.xls for part numbers and ordering information):

	40 small signal diodes  
	1 5 mm dome LED  
	1 510 ohm, 1/8 watt resistor  
	34 Matias quiet linear key switches  
	2 16-position rotary DIP switches  
	1 Teensy 2.0 module  
	1 Stenokey circuit board  
	1 USB A to USB mini-B cable  
	8 M3 heat set inserts  
	8 M3 x 12 mm pan head machine screws  

	You will also need the following items:

	Soldering iron with a fine tip  
Solder (rosin core recommended)  
Liquid soldering flux (recommended)  
Nippers (a.k.a. side cutters) or wire cutters  
Sharp knife for scraping plastic  
Fingernail file for cleaning up edges of plastic  
Cyanoacrylate glue (may not be necessary)  
Drill with 1/4" and 1/8" drill bits (may not be necessary)  
Sandpaper for cleaning up the surfaces of the keys (may not be necessary)  
99% Isopropyl Alcohol (optional)  
Electronics prototype board (for soldering pins to Teensy)  
Electrical multimeter (recommended)  
Needle nose pliers (may not be necessary)  
Paper towel (optional)  
Safety glasses (required)  
Phillips head screwdriver for M3 screws    

2.  Print the Stenokey key tops, case top, key matrix and case base, or have someone print them for you.  See the notes in the StenokeyKeys.scad and StenokeyCase.scad files for information on printing these components.  

	You have options in terms of which side of the Stenokey that the USB cable will plug into, and in terms of which side the three interface holes (the power LED and the two rotary switches) will be on.  You also have several options when printing the key tops.  

	Clean up the printed parts as necessary; make them pretty.

3.  Check to make sure that the circuit board fits down onto the 
pegs that stick out of the top of the Stenokey base.  You should end up with the top surface of all 8 pegs almost flush with the top surface of the circuit board.  If you cannot get the circuit board to fit, you may need to chase (i.e. drill out) any tight holes on the circuit board with a 1/4" drill bit.

	Once you've checked the fit of the circuit board, remove it from the base.

	Check to make sure that an M3 screw will fit into each screw hole in the base.  A screw should slide easily into each hole.  If any of the holes are tight, chase them with a 1/8" drill bit. 

4.  Check the fit of the key switches in the key matrix.  They should fit snugly so that they won't fall out when you turn everything over while building the Stenokey.

	Be sure to insert the bottom of the key switches through the top surface of the key matrix.  (The bottoms of the key switches have pins protruding from them.  The top surface of the key matrix is flat; it has no ribs.)

	If any of the key switches are loose, you might consider using a drop of cyanoacrylate glue to glue each loose switch in place.  Be sure that each switch is fully seated before you glue it.  Use glue sparingly.  The Matias key switches are not sealed, and if glue wicks into a switch, it will ruin the switch.

	If any of the key switches won't fit at all, DO NOT FORCE the switches, use a sharp knife to scrape a few times along each side of the key switch hole.  Repeat as necessary until a switch can be pressed into place.  Repeat as necessary for the remaining switches and mount all of the switches in their holes.  

	Be sure to orient the switches so that the pins that stick out of the bottom of each switch are oriented towards (i.e. are closer to) the top edge of the key matrix (i.e. the edge that is opposite from the 4 vowel keys).  Make sure that all key switch pins are not bent and are sticking straight out from the bottoms of the switches.

	Check the fit of the key matrix on the top of the circuit board.  Each pin should fit down into its corresponding hole in the circuit board.  Be careful to avoid bending any pins.  If some of the pins won't come through the board, don't force them to fit; separate the key matrix from the circuit board, straighten any bent pins and try again.  Remove the key matrix from the board when you are done.

5.  Check to make sure that the Teensy is working.  Connect the Teensy to your computer using the USB mini-B cable.  The LED on the Teensy should start blinking.  (Each Teensy is shipped preprogrammed with a blink program.)  Disconnect the Teensy.

6.  Solder the Teensy onto its headers.  The headers are provided as a longer strip of snappable header pins.  Break off two headers of 12 pins each.  It may be helpful to use needle nose pliers to grasp the retainer on the pin next to where you want to break the strip.  Then bend the strip, with your fingers close to the pliers, until it breaks.

	Watch the video and follow the instructions on the following web page to ensure that you solder the header pins correctly.

	[https://www.pjrc.com/soldering-pins-on-to-your-teensy/](https://www.pjrc.com/soldering-pins-on-to-your-teensy/)

	If you have liquid flux, use it, but use it sparingly.  There is seldom enough flux provided in the core of rosin core solder to solder header pins, and the extra flux will help to guarantee that you get a good solder joint every time.

	Note that while the Stenokey circuit board has additional holes matching the Teensy footprint, only pins adjacent to the long edges of the Teensy are actually used; there is no need to place pins in the remaining holes.

7.  READ through this step completely before proceeding.  DO NOT solder any of the key switches until after you have completely tested the circuit board (in step 8).  

	In this step, you will solder all components except the key switches to the circuit board.  Components must be mounted through the top of the board and must be soldered from the back side of the board.  Be sure to orient all components correctly.  

	Each diode has a black bar on it, marking the cathode.  The bar must match up with the white bar shown on the circuit board.  You can save time bending the leads of the resistor and diodes by using a lead bending jig.  Various such jigs are available for printing on Thingiverse, or you can print the file LeadBender.stl that is included with this project.  That jig is sized specifically for the axial components and the 8 mm lead spacing used on the Stenokey circuit board.  

	Because there are so many diodes to solder to the circuit board, it is easy to make a mistake and place some of the diodes on the board backwards.  The diodes are normally supplied in a band with tape on each end.  If you cut the tips of the leads on the cathode side to remove them from the tape, but pull the leads from the tape on anode side, you will end up with diodes that have shorter leads on their cathodes.  The differing lead lengths will make it easier to make sure that you have oriented the diodes correctly when you are pushing the leads through the circuit board. 

	The LED in the BOM has one shorter lead and an indent on the lip around the molding which mark the cathode.  Match that lead up with the line to the left of the circle on the circuit board.  (Note that this scheme for marking the cathode on an LED is not universal.  If you have substituted some other LED for the one in the BOM, then you can use the continuity/diode test feature on a multimeter to check the polarity of the LED, if you are unsure which lead is the cathode.  The meter should show a reading of about 1.8 V when the cathode is connected to the negative (black) lead of the meter.)

	The Teensy must be installed with its USB connector facing the adjacent edge of the circuit board.  Be sure to solder the Teensy to the side of the board that you chose when you printed the Stenokey cover.  Don't get confused by looking at the top cover when it is lying on its top surface.  Flip it right side up, or mate it to the base to avoid confusion.

	Make sure that each component is pressed firmly against the top surface of the board before applying solder from the bottom, otherwise you will end up with tilted components and it will be hard to straighten them out later.  While pressing on the body of the axial components from the top of the board, you can splay the leads of the resistor or diodes to 45 degrees.  That will hold them in place while you solder.

	Do not attempt to place a large number of the axial components before soldering them.  That will likely only cause you trouble.  Place a few or perhaps as many as a half dozen components at a time, then solder them and trim their leads.  Repeat until you have soldered the resistor and all of the diodes.  

	It is easier to correct soldering errors on components that have just two pins.  When soldering a component with additional pins, it helps to solder a single pin in one corner of the component first.  Once you have done that, make sure that the component is still seated properly.  If not, reheat the pin or lead and reseat the component.  Then solder a single pin in the opposite corner of the component next.  Once again, check to make sure that the component is still seated properly.  Correct as necessary before proceding.  Once you are happy with the seating of the component, check the orientation of the component one last time, then solder the remaining pins.

	The rotary switches must be installed with the number '0' on the dial oriented towards the left of the circuit board.

	If you have printed the version of the cover with the interface holes on the left, place the LED in slot D41, the resistor in slot R1 and the rotary switches in slots SW37 and SW38 on the left.  Leave the slots D42, R2, SW35 and SW36 empty.  

	Alternatively, if you have printed the version of the top cover with the interface holes on the right, place the LED in slot D42, the resistor in slot R2 and the rotary switches in slots SW35 and SW36 on the right.  Leave the slots D41, R1, SW37 and SW38 empty.  

	After soldering some of the components, the leads will likely get in the way.  Use side cutters to trim the ends of leads which protrude from the solder on the bottom of the board.  Be sure to use safety glasses when nipping off leads or pins, they can fly into your eyes causing an abrasion or worse.  Always choose safety over a trip to the hospital.  

	When you are done soldering all components on the circuit board, be sure to trim any remaining leads or pins.  No pin or lead should protrude more than a millimeter from the bottom of the circuit board.

8.  Check your work before continuing.  The easiest mistake to make is to install a diode backwards and while that won't cause any permanent damage, Stenokey will not work correctly, and that may just ruin your day.  Make sure that the black bar on all diodes is on the left.  Make sure that the indent on the rim on the LED is also on the left.  Make sure that the rotary switches are also oriented with their zero positions to the left. 

	Run through the "Programming and Testing the Stenokey Circuit Board" procedure as described in the file Stenokey_Test.pdf before continuing with building the Stenokey.  You must make sure that the Stenokey is operational before soldering down the key switches.

9.  It is generally safe to leave rosin based flux on a circuit board.  However, if you have used a more aggressive flux, clean the board according to the manufacturer's recommendation.  If you wish to clean up the board and you've used rosin based flux on it, you can use 99% isopropyl alcohol and and old tooth brush.  It can take several minutes to dissolve and remove hardened flux.  Wipe off dissolved flux with a paper towel, before it rehardens.

	Alcohol is a flammable liquid.  Use at your own risk.  Only use in a well ventilated area away from heaters, lights and open flame.  Most commercial flux removers are also flammable.  Be sure to follow the manufacturer's instructions if you use a flux remover.

	While removing flux from the bottom of the board, don't forget the Teensy on the top of the board.  It is important to remove the flux from the Teensy before soldering on the key switches, rather than after.

	Be careful to avoid getting alcohol or flux remover near the rotary switches on the top side of the circuit board.  The alcohol can wick into the switches and flux residue can gum up the works, ruining the switches.  

10.  Fit the key matrix to the circuit board then solder the key switches to the board.  Solder starting in the middle of the matrix and working outward.  It is important to make sure that each key switch is flat against the circuit board, or you will end up with a non-level bed of keys and the Stenokey case will not fit properly.  Because the key matrix and circuit board are quite flexible, you should apply pressure forcing each key switch against the board as you solder its pins.

	Once you have soldered all of the key switches to the board, connect the USB cable and check you work.  Make sure that each and every key switch works correctly.  Depending on the state that you left things in when testing before, your key presses will appear either in the Arduino Serial Monitor or the Plover Paper Tape display.  If any of the key switches is not registering key presses, it is most likely a cold solder joint or an unsoldered joint on the key switch that is the culprit.  Refer to the troubleshooting tips in the Stenokey testing document for assistance.  Remove the USB cable once you have finished testing.

11.  Once you have tested all of the key switches, you can remove the flux from the back of the board.  Be sure to use alcohol or flux remover sparingly to avoid having it migrate to the top of the board.  The Matias key switches are not sealed.  As with the rotary switches, alcohol or flux remover can wick into the key switches and flux residue can get into the switches and ruin them.  

12.  Using a hot soldering iron, insert the 8 heat set inserts into the holes in the pads on the top cover.  Push each insert down into its hole, until its top surface is flush with the top of its pad, or just slightly below.  Use gentle force and push straight down with the soldering iron, so that the inserts don't end up skewed.  

	If some plastic oozes up while inserting the heat set inserts, wait until the molten plastic has hardened, but is still warm (about a minute).  Then slice off the excess plastic with a sharp knife.  The plastic cuts most easily when it is warm, but not soft.  If you need to push an insert deeper or right a slightly off skew insert, you shouldn't have any trouble.  The inserts are quite forgiving as long as you use gentle force.  

13.  Mount the circuit board onto the pegs on the base of the case.  Fit the top cover to the base then screw in the 8 M3 screws to affix the cover to the base.  Do not over tighten the screws.  Insert the key tops into the key switches.  At this point, the Stenokey is complete.  Plug in the USB cable and the Stenokey is ready to use. 

14.  (Optional)  As seen in pictures of the Stenokey, a logo has been affixed to the case.  The logo was cut from standard sign making adhesive vinyl film using a craft cutter, Cricut Explore.  The file StenoKeyLogo.svg (in the main distribution directory) was imported into Cricut Design Space, and resized there.  The recommended size is approximately 75 mm x 6 mm.  (The object height can be set to 1/4", resulting in a width of just under 3".)     

	The logo will need to be transferred to transfer tape and it will need to be weeded before applying the logo to the Stenokey body.  These techniques are beyond the scope of this document, however there are numerous short tutorials on weeding, reverse weeding and applying vinyl labels, which are available on YouTube and other sites on the Internet.

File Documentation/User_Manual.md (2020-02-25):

# The Stenokey User's Manual

Copyright © 2017, 2020, Mike Ady  
This file is part of the open source Stenokey project.  
This file is licensed under the Creative Commons Attribution-ShareAlike license.

The Stenokey keyboard emulates a stenographic machine.  It works much like any USB keyboard on a desktop PC.  It connects to any desktop or laptop PC through a USB port using a USB A to USB mini-B cable.  You will need to install the open source Plover program or other commercial stenography software on your PC to use the Stenokey.

## Configuring Stenokey

The Stenokey has two rotary switches which can be used to configure the keyboard.  If the rotary switches have been installed on the left side of the keyboard, then the protocol switch is on the left and the brightness switch for the power LED is on the right.  (These switches are in the opposite order if they have been installed on the right side of the keyboard.)  

To change the settings on the board, you will need a flat head jeweler's screwdriver (or perhaps an eyeglass repair or sewing machine screwdriver) with a blade that is no more than 2.5 mm (0.1") wide.  

There are 5 steno protocols available, numbered 0 through 4:

0  Diagnostic (displays the row and column of each pressed key)  
1  NKRO Keyboard  
2  Gemini PR  
3  TX Bolt  
4  ProCAT  

There are 8 power LED brightnesses, from 0 through 7.  The LED is off in position 0, and fully on in position 7.

On both switches, switch position 0 is at the 9 o'clock position and the numbers increase with each detente as the switch is turned clockwise.

Select one of the non-diagnostic protocols before continuing.  All of the non-diagnostic protocols work equally well with Plover, though you may want to select a specific protocol if you have commercial software that you want to use instead of, or in addition to Plover.  

In general, NKRO keyboard mode is not recommended, since choosing it will cause Plover to intercept and translate keystrokes on both the Stenokey and the PC's own keyboard.  All of the other protocols use the USB serial interface, and they allow you to use the Stenokey in addition to your PC's keyboard without having to enable and disable Plover to switch between keyboards.

At the time of writing, there was an issue with Plover's support for numeric keystrokes on NKRO keyboards.  This problem was corrected in version 4.0.0.dev3.  Any later stable release should also have this fix.  

[The diagnostic protocol also uses the USB serial interface but it is not supported by Plover.  You shouldn't need to use the diagnostic protocol, but if you do want to use it for troubleshooting, you will need a serial monitor program to view the output.  You can install the Arduino software on your PC for that purpose.  See the Stenokey Programming and Testing Manual for further information.]

## Plover Software Installation

If you built your Stenokey keyboard yourself, then you will likely already have Plover installed on your PC and you can skip this section.  There is also no need to install Plover if you plan to use commercial stenography software exclusively.

To install Plover, open an Internet browser on your PC then open the following web page:

[http://github.com/openstenoproject/plover/wiki/Installation-Guide](http://github.com/openstenoproject/plover/wiki/Installation-Guide) 

Follow the instructions on that page and download the "latest stable version" for your operating system.  Follow the instructions specific to your operating system to install the software.  

## Configuring Plover

Note:  On Windows, you will need to run Plover "as administrator" to allow Plover to translate keystrokes for your word processing software, etc.  To run Plover as administrator, right click on the Plover shortcut and select "Run as administrator".

Connect the Stenokey to a USB port on your PC if you haven't done so already.  Open Plover, click on the Configure button then select the Machine tab on the dialog that opens.  Click on the "Machine:" drop down listbox and select the protocol that you configured the Stenokey for.  If you have configured the Stenokey for NKRO Keyboard mode, select "Keyboard" as the machine type.

All of the non-NKRO protocols use the USB serial interface and you will need to select a serial port for Plover to connect to.  Click on the Scan button to scan for available serial ports on your PC.  If more than one serial port appears in the "Port" drop down listbox and you aren't sure which one is associated with the Stenokey, unplug the Stenokey and click on the Scan button in Plover again.  One serial port should disappear and that should be the Stenokey's port.

Once you've set the serial port, use the defaults for the rest of the settings on the Machine tab and click on OK to dismiss the Configuration dialog box.

## Using the Stenokey

Select the Enable radio button in Plover to activate it.  Open a text editor or word processor and start typing on the Stenokey.  Plover will intercept your keystrokes on the Stenokey and translate them into syllables, words and phrases in your document.  

In Keyboard mode, Plover will also intercept keystrokes on your PC or laptop keyboard (but only the ones that it recognizes).  Disable Plover output when you want to use your regular keyboard without Plover interfering.

On Windows, you may find that Stenokey's keystrokes are appearing in Plover's paper tape window, but they fail to appear in which ever text editor or word processor window that has the focus.  In this case, you will need to exit Plover then rerun it "As Administrator".  Closing the Plover windows does not cause Plover to exit.  To quit Plover, open the tray on the taskbar and right click on the Plover icon (a stylized steno key) then select Quit Plover.

## Troubleshooting

If you are having trouble seeing Stenokey keystrokes in your word processor, verify that you have selected the right protocol and serial port.  (Refer to the Configuring Plover section above.)  You may need to disconnect and reconnect.  To do that, click on the "recycle" button in Plover.  Make sure that Plover output is enabled.  That is, make sure that the Enable radio button in Plover is selected.  

The Plover paper tape display is you friend when it comes to tracking down connection issues.  On Windows, if you find that Stenokey's keystrokes are appearing in Plover's paper tape window, but they fail to appear in which ever text editor or word processor window that has the focus, you will need to exit Plover then rerun it "As Administrator".  Closing the Plover windows does not cause Plover to exit.  To quit Plover, open the tray on the taskbar and right click on the Plover icon (a stylized steno key) then select Quit Plover from the pop up menu.  After exiting Plover, restart it making sure to run it as administrator.
 
## What Next?

If you already know some steno, you likely know what you want to do next.  If you're a total newbie to steno, the most important thing to learn first is how to place your fingers on the home row of the keyboard.  The "Learn Plover!" book by Zack Brown will teach you that and many other important skills while paying special attention to the Plover program.  The book is highly recommended and is available on line in paperback at Amazon.com.  You can also view the book for free on line here:

[https://sites.google.com/site/ploverdoc/home](https://sites.google.com/site/ploverdoc/home)

Exercises to go with the book are available here:

[http://www.tranklements.com/PloverLearn/](http://www.tranklements.com/PloverLearn/)

The Steno Tutor program by Emanuele Caruso is also highly recommended.  Steno Tutor will present you with repetitive exercises to help you to learn the steno keyboard layout and to learn how to chord.  Steno Tutor is open source and you can download it from here:

[https://github.com/caru/StenoTutor](https://github.com/caru/StenoTutor)

Follow the instructions on that page to install the package and run it.  

The documentation for Steno Tutor is somewhat sparse.  To change settings, you will need to edit the "session.properties" file with a text editor.  That file is found in the data sub directory of the Steno Tutor program, (specific to your operating system).  

Steno Tutor will not proceed unless you have entered exactly the word that it has highlighted.  Use the asterisk key (on the Stenokey) to delete incorrect entries.  The Backspace key on your regular keyboard can be used to delete words one character at a time, but that is less useful.  

Use the Tab key on your regular keyboard to pause Steno Tutor.  (You can stroke "TA*B" on the Stenokey to the same effect if you are also using Plover.)  Once Steno Tutor is paused, striking any key or chord on the Stenokey will start Steno Tutor's timer again.

Steno Tutor expects words to be typed in lower case.  If you find that characters are appearing in upper case, use the Caps Lock key on your regular keyboard to toggle the case.  You may need to strike the Caps Lock key twice for it to take effect.  

Links to additional learning resources are available here:

[http://stenoknight.com/wiki/Practice](http://stenoknight.com/wiki/Practice)

and here:

[https://github.com/openstenoproject/plover/wiki/Learning-Stenography](https://github.com/openstenoproject/plover/wiki/Learning-Stenography)

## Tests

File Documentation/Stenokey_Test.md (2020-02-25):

# Programming and Testing the Stenokey Circuit Board

Copyright © 2017, Mike Ady  
This file is part of the open source Stenokey project.  This file is licensed under the Creative Commons Attribution-ShareAlike license.

It is important to check that the Stenokey circuit board is working before soldering down the key switches and the key matrix in case there is a problem that the key matrix might hide.  

The most important test that you can perform is a full visual inspection of the components on the board.  Make sure that the black bar on each and every diode is on the left.  Make sure that the indent in the rim of the LED is on the left and that the "0" positions of the option switches are also on the left.

To test the Stenokey circuit board, you will need to install the Arduino and Teensyduino software to program the Teensy micro controller.  You will need to install and configure the Plover software to fully test all of the features of the Stenokey circuit board.  Instructions are provided below. 

You will need a paper clip or a short length of wire to test with.  The paper clip or wire will be used to simulate key presses.  You will need a small slot head jeweler's screwdriver or similar screwdriver to change settings on the rotary switches.  

If you run into a problem with the circuit board, there is a section on troubleshooting towards the end of this document.  

For troubleshooting, you may find a multimeter useful.  For repair, you will need a soldering iron, solder, flux (optional), and solder wick or a desoldering tool.

## Programming and Testing

1.  Open an Internet Browser on your PC, then follow the instructions on the following web page to download and install the Arduino and Teensyduino software:

	[https://www.pjrc.com/teensy/td_download.html](https://www.pjrc.com/teensy/td_download.html)

	Be sure to install all drivers and other software that the installers ask you to install.

	If you haven't done so already, you will need to download and install the Plover application.  Open the following web page and scroll down to the bottom.  Click on "Download Latest Stable", which will redirect you to the download page:

	[http://www.openstenoproject.org/plover/](http://www.openstenoproject.org/plover/)

	Download the appropriate version for your operating system.  For some versions of Linux, you may need to build Plover from source.

2.  Clear an area on your desk to place the Stenokey circuit board on.  Move any bits of wire or other conductive materials clear away from the circuit board to avoid shorting out the board.  Place the Stenokey on top of a hand cloth or a sheet of cardboard to avoid scratching your table.  Remove any metallic jewelry on your wrists such as watches or bracelets to avoid shorting anything out while testing.

3.  Open the StenoFW.ino project in the Arduino application by double clicking on it, or run the Arduino application and open the firmware file by selecting Open...  from the File menu.  The StenoFW.ino project can be found in the Firmware/StenoFW sub-directory of the Stenokey distribution.

4.  Open the Tools menu in the Arduino application and select the menu item starting with "Board:".  Make sure that "Teensy 2.0" is selected.

5.  Open the Tools menu and select the menu item starting with "USB Type:".  Make sure that "Serial + Keyboard + Mouse + Joystick" is selected.  

6.  Click on the check mark on the toolbar to compile the Stenokey firmware.  Once the firmware has compiled successfully, the Teensy loader program will pop up.  (Don't try to upload the firmware to the Teensy using the Arduino application's Upload functionality; it won't work.)  Instead, follow the instructions presented by the Teensy application and press the button on the Teensy to start the upload process. 

7.  Make sure that the protocol switch, (SW35 or SW37) is set to "0" to select the diagnostic output protocol.  Open the Tools menu in the Arduino application and select Serial Monitor.  Use a paper clip or piece of wire to short out the two pads on one of the key switches.  You should see one or more lines with a 2 digit number appear in the Serial Monitor.  
 
	Note that the Stenokey does not emit the key code for a key press until the key is released.  When chording, the key codes are not emitted until all depressed keys are released.
  
	The first digit on each line in the Serial Monitor should be the key switch's row number (numbered 1 through 4, from top to bottom).  The second digit should be the key switch's column number (numbered 1 through A (A=10) from left to  right).  The vowel keys show the following codes, in order, from left to right:  41, 42, 46, 47.

8.  Verify the LED brightness switch (SW36 or SW37) by turning the switch to positions 0 through 7.  Position 0 is off, while position 7 is full brightness.

9.  Verify the protocol switch.  To do this, you will need to switch to each of the protocol settings then use Plover's Paper Tape display to verify that it is seeing the keystrokes that correspond to the key switches that you short out.

	The Protocol switch settings are as follows:

	0 Diagnostic protocol (view in the Serial Monitor)  
	1 Keyboard emulation (view in Plover)  
	2 Gemini protocol (view in Plover)  
	3 TXBolt protocol (view in Plover)  
	4 Procat protocol (view in Plover)  

	Note that protocol 0 is not supported by Plover, while protocol 1 is not visible from the Arduino Serial Monitor.  Also, protocols 2, 3 and 4 will generate a number of random looking characters with each key press when viewed from the Ardiuno Serial Monitor.  

	To verify that protocols 1 - 4 are being properly encoded by the rotary switch, close the Arduino Serial Monitor then open the Plover app.  On Windows, Plover must be run with administrator privilege to work properly.  For each protocol that you test, you must change both the protocol setting on the circuit board and change the protocol in Plover.  

	To set up Plover for a particular protocol, click on the Configure button on the Plover toolbar.  The Plover Configuration dialog will open.  Select the Machine tab.  Select a protocol to test with from the "Machine" drop down list box.  For the serial protocols (all protocols except for Keyboard), you will need to select the serial port and baud rate.  

	You can find out the serial port that the Teensy is connected to by opening the Arduino Tools menu.  The serial port will be listed on the line with the text "Port:".  Select the same port in Plover.  If the port does not appear in the Port drop down list box in Plover, click on the Scan button to scan for serial ports.  Finally select 115200 from the Baudrate drop down list box, then click on OK to dismiss the dialog.  Back in Plover, click on the reconnect button to make sure that Plover will see your keystrokes on the Stenokey. 

	You only need to check a few key switches on the circuit board to make sure that a particular protocol selection is working.  Plover should display the characters corresponding to the key switch pads that you short out then release.  See the following table:

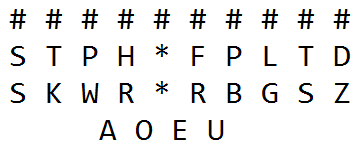
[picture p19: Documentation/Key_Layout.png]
	

11.  Once you have checked out everything on the Stenokey circuit board and everything is working, UNPLUG THE USB CABLE then continue with the Stenokey build instructions to complete assembly of the Stenokey. 

## Background

It is important to understand a little about how the Stenokey circuit board works to be able to troubleshoot it.

The Stenokey is a simple key switch matrix with a micro controller that reads the states of all of the switches and transmits their states to a PC.  The circuit board has wires arranged in rows and columns with a key switch and a diode wired to the intersection of most of the row and column wires.  

The micro controller scans the keys by applying a voltage to a single row wire at a time.  It reads the state of each switch in a row by checking the voltage on each column wire, one wire at a time.  Of course, the connections between the micro controller and the switches are where most of the problems with soldering the circuit board occur.

Each switch is wired in series with a diode.  The purpose of the diodes is to prevent current from flowing through the key matrix in the wrong directions when two or more keys are pressed at the same time.  The diodes allow the micro controller to scan each key switch individually, without any cross talk between the switches.

The rotary option switches work the same way as the key switches, except that each rotary switch is connected to three different column wires through three different diodes.  The micro controller reads the rotary switches in exactly the same manner as it reads the key switches.

## Troubleshooting Tips

(If you can read an electrical schematic and you have a multimeter, the Stenokey schematic is available in PDF format in the Documentation sub-directory of the Stenokey distribution.)  

1.  If you get no response from the Teensy download program when you press the reset button on the Teensy, you may have a bad connection to your PC or you may have a short somewhere that is pulling down the power to the Teensy.
	- Make sure that the USB connector is fully inserted on both ends.  
	- Try another port on your PC.
	- Try a different USB cable.
	- Verify all solder connections, and make sure that there are no solder bridges or other unwanted conductive paths.  

2.  If all of the key switches in a particular row or column are not working, you probably have a cold solder joint or even a non-existent solder joint on the Teensy end.  

	Refer to the following diagram to determine which pin or pins is the most likely culprit. 

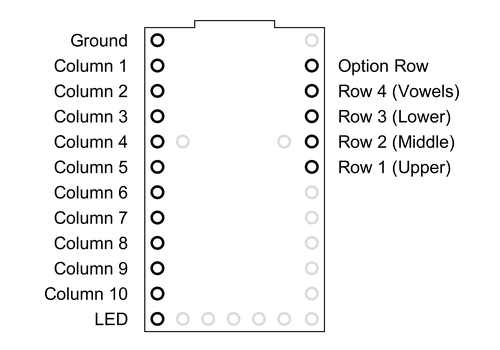
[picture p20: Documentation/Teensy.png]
	

	Note that the first two vowel keys are on columns 1 and 2, while the second two vowel keys are on columns 5 and 6.  

	The simplest fix, if you have liquid flux, is to apply flux to the bad joint or joints, then re-heat the joint with your soldering iron.  If you don't have flux, it is best to remove as much of the solder on the joint as possible using solder wick or a desoldering tool, then reapply fresh solder to the joint.  Be sure to check both the bottom and top solder joints on the Teensy module.
 
3.  If some key switch or switches don't work and the issues don't appear to be correlated, then the most likely problem is a cold joint on the diode that is adjacent to each problem key switch.  As mentioned previously, try to repair the problem by applying flux to the diode joints and then reheating the solder.  Alternatively, remove the solder with solder wick or a desoldering tool and resolder the joints.

	It is unlikely but it is also possible that you could have a bad diode, and you could try replacing it.  If you have a multimeter, you can verify that a diode is working by selecting the continuity/diode checking function on your meter.  The meter should show a voltage drop of about 0.6 V with the black lead on the cathode (black band) and the red lead on the anode.  With the leads swapped, the meter should show no connection.  If the cathode is not on the left, remove it and resolder it in the correct orientation.

4.  If the LED doesn't light, no matter what position the brightness rotary switch is in, then it is most likely that the LED has been installed backwards or it is burned out.  (It is also possible that the brightness rotary switch isn't working at all.  See troubleshooting tip 5, below.)

	- If you have a multimeter, you can verify that a LED is working by selecting the continuity/diode checking function on your meter.  The meter should show a voltage drop of about 1.8 V with the black lead on the cathode and the red lead on the anode.  With the leads swapped, the meter should show no connection.  If the cathode is not on the left, then the LED has been installed backwards;  if so, remove it and resolder it in the correct orientation.  
	- It is also possible that you have a cold solder joint on the LED, the resistor, or the Ground or LED pins on the Teensy module.  The simplest fix, if you have liquid flux, is to apply flux to the bad joint or joints, then re-heat each joint with your soldering iron.  If you don't have flux, it is best to remove as much of the solder on the joints as possible, using solder wick or a desoldering tool, then reapply fresh solder to the joints.  

5.  If neither of the rotary switches is working at all, then the problem is most likely a bad solder joint on the "Option Row" pin of the Teensy module.  See troubleshooting tip 2 above for further details.

6.  If one or both rotary switches are not operating correctly, then the problem is most likely a bad solder joint on either the rotary switches or their associated diodes.  Diodes D33, D34 and D35 are associated with the protocol switch (SW35 or SW37).  Diodes D38, D39 and D40 are associated with brightness switch (SW36 or SW38).  See troubleshooting tip 3 above for further details.

7.  If the Arduino software fails to build the Stenokey firmware, it is most likely an incompatibility that has arisen between the Arduino or Teensyduino libraries and the Stenokey firmware.  You can get help for the Arduino libraries on the Arduino forum.  You can get help for the Teensyduino libraries at PJRC.  You can also post an issue to the Stenokey project on Github.  

	As an alternative to building the Stenokey firmware from scratch, you can load the pre-built firmware instead.  The pre-built firmware is in the Firmware sub-directory of the Stenokey distribution in the file StenoFW.ino.hex.  To program the Teensy, open the Teensy download program and select "Open HEX File" from the program's File menu.  Open the above mentioned hex file to load it into the Teensy program.  Press the reset button on the Teensy to program it. 

8.  If shorting one key switch causes the micro controller to show two or more key presses at the same time, the problem is most likely a solder bridge on the Teensy module.  Carefully check the pins on both the top and bottom of the Teensy to make sure that excess solder isn't connecting any of the pins together.  If there is excess solder, remove it with solder wick or a desoldering tool.  If you remove too much solder, resolder the affected joints, but apply solder sparingly.

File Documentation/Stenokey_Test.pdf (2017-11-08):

# Programming and Testing the Stenokey Circuit

# Board

Copyright © 2017, Mike Ady
This file is part of the open source Stenokey project.
This file is licensed under the Creative Commons Attribution-ShareAlike license.

It is important to check that the Stenokey circuit board is working before soldering down the key switches and the key matrix in case there is a problem that the key matrix might hide.

The most important test that you can perform is a full visual inspection of the components on the board. Make sure that the black bar on each and every diode is on the left. Make sure that the indent in the rim of the LED is on the left and that the "0" positions of the option switches are also on the left.

To test the Stenokey circuit board, you will need to install the Arduino and Teensyduino software to program the Teensy micro controller. You will need to install and configure the Plover software to fully test all of the features of the Stenokey circuit board. Instructions are provided below.

You will need a paper clip or a short length of wire to test with. The paper clip or wire will be used to simulate key presses. You will need a small slot head jeweler's screwdriver or similar screwdriver to change settings on the rotary switches.

If you run into a problem with the circuit board, there is a section on troubleshooting towards the end of this document.

For troubleshooting, you may find a multimeter useful. For repair, you will need a soldering iron, solder, flux (optional), and solder wick or a desoldering tool.

# Programming and Testing

Open an Internet Browser on your PC, then follow the instructions on the following web page to download and install the Arduino and Teensyduino software:

https://www.pjrc.com/teensy/td_download.html

Be sure to install all drivers and other software that the installers ask you to install.

If you haven't done so already, you will need to download and install the Plover application. Open the following web page and scroll down to the bottom. Click on "Download Latest Stable", which will redirect you to the download page:

http://www.openstenoproject.org/plover/

1.

Download the appropriate version for your operating system. For some versions of Linux, you may need to build Plover from source.

Clear an area on your desk to place the Stenokey circuit board on. Move any bits of wire or other conductive materials clear away from the circuit board to avoid shorting out the board. Place the Stenokey on top of a hand cloth or a sheet of cardboard to avoid scratching your table. Remove any metallic jewelry on your wrists such as watches or bracelets to avoid shorting anything out while testing.

2.

Open the StenoFW.ino project in the Arduino application by double clicking on it, or run the Arduino application and open the firmware file by selecting Open... from the File menu. The StenoFW.ino project can be found in the Firmware/StenoFW sub-directory of the Stenokey distribution.

3.

Open the Tools menu in the Arduino application and select the menu item starting with "Board:". Make sure that "Teensy 2.0" is selected.

4.

Open the Tools menu and select the menu item starting with "USB Type:". Make sure that "Serial + Keyboard + Mouse + Joystick" is selected.

5.

Click on the check mark on the toolbar to compile the Stenokey firmware. Once the firmware has compiled successfully, the Teensy loader program will pop up. (Don't try to upload the firmware to the Teensy using the Arduino application's Upload functionality; it won't work.) Instead, follow the instructions presented by the Teensy application and press the button on the Teensy to start the upload process.

6.

Make sure that the protocol switch, (SW35 or SW37) is set to "0" to select the diagnostic output protocol. Open the Tools menu in the Arduino application and select Serial Monitor. Use a paper clip or piece of wire to short out the two pads on one of the key switches. You should see one or more lines with a 2 digit number appear in the Serial Monitor.

Note that the Stenokey does not emit the key code for a key press until the key is released. When chording, the key codes are not emitted until all depressed keys are released.

The first digit on each line in the Serial Monitor should be the key switch's row number (numbered 1 through 4, from top to bottom). The second digit should be the key switch's column number (numbered 1 through A (A=10) from left to right). The vowel keys show the following codes, in order, from left to right: 41, 42, 46, 47.

7.

Verify the LED brightness switch (SW36 or SW37) by turning the switch to positions 0 through 7. Position 0 is off, while position 7 is full brightness.

8.

Verify the protocol switch. To do this, you will need to switch to each of the protocol settings then use Plover's Paper Tape display to verify that it is seeing the keystrokes that correspond to the key switches that you short out.

The Protocol switch settings are as follows:

### 0 Diagnostic protocol (view in the Serial Monitor)

9.

### 1 Keyboard emulation (view in Plover)

### 2 Gemini protocol (view in Plover)

### 3 TXBolt protocol (view in Plover)

### 4 Procat protocol (view in Plover)

Note that protocol 0 is not supported by Plover, while protocol 1 is not visible from the Arduino Serial Monitor. Also, protocols 2, 3 and 4 will generate a number of random looking characters with each key press when viewed from the Ardiuno Serial Monitor.

To verify that protocols 1 - 4 are being properly encoded by the rotary switch, close the Arduino Serial Monitor then open the Plover app. On Windows, Plover must be run with administrator privilege to work properly. For each protocol that you test, you must change both the protocol setting on the circuit board and change the protocol in Plover.

To set up Plover for a particular protocol, click on the Configure button on the Plover toolbar. The Plover Configuration dialog will open. Select the Machine tab. Select a protocol to test with from the "Machine" drop down list box. For the serial protocols (all protocols except for Keyboard), you will need to select the serial port and baud rate.

You can find out the serial port that the Teensy is connected to by opening the Arduino Tools menu. The serial port will be listed on the line with the text "Port:". Select the same port in Plover. If the port does not appear in the Port drop down list box in Plover, click on the Scan button to scan for serial ports. Finally select 115200 from the Baudrate drop down list box, then click on OK to dismiss the dialog. Back in Plover, click on the reconnect button to make sure that Plover will see your keystrokes on the Stenokey.

You only need to check a few key switches on the circuit board to make sure that a particular protocol selection is working. Plover should display the characters corresponding to the key switch pads that you short out then release. See the following table:

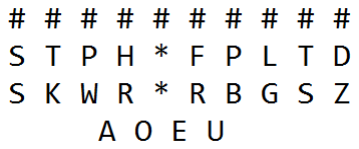
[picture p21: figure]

Once you have checked out everything on the Stenokey circuit board and everything is working, UNPLUG THE USB CABLE then continue with the Stenokey build instructions to complete assembly of the Stenokey.

10.

# Background

It is important to understand a little about how the Stenokey circuit board works to be able to troubleshoot it.

The Stenokey is a simple key switch matrix with a micro controller that reads the states of all of the switches and transmits their states to a PC. The circuit board has wires arranged in rows and columns with a key switch and a diode wired to the intersection of most of the row and column wires.

The micro controller scans the keys by applying a voltage to a single row wire at a time. It reads the state of each switch in a row by checking the voltage on each column wire, one wire at a time. Of course, the connections between the micro controller and the switches are where most of the problems with soldering the circuit board occur.

Each switch is wired in series with a diode. The purpose of the diodes is to prevent current from flowing through the key matrix in the wrong directions when two or more keys are pressed at the same time. The diodes allow the micro controller to scan each key switch individually, without any cross talk between the switches.

The rotary option switches work the same way as the key switches, except that each rotary switch is connected to three different column wires through three different diodes. The micro controller reads the rotary switches in exactly the same manner as it reads the key switches.

# Troubleshooting Tips

(If you can read an electrical schematic and you have a multimeter, the Stenokey schematic is available in PDF format in the Documentation sub-directory of the Stenokey distribution.)

If you get no response from the Teensy download program when you press the reset button on the Teensy, you may have a bad connection to your PC or you may have a short somewhere that is pulling down the power to the Teensy.

Make sure that the USB connector is fully inserted on both ends.
Try another port on your PC.
Try a different USB cable.
Verify all solder connections, and make sure that there are no solder bridges or other unwanted conductive paths.

1.

If all of the key switches in a particular row or column are not working, you probably have a cold solder joint or even a non-existent solder joint on the Teensy end.

Refer to the following diagram to determine which pin or pins is the most likely culprit.

2.

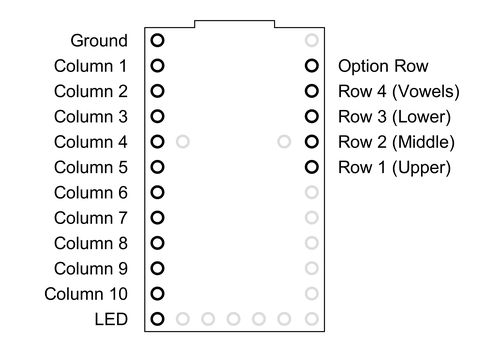
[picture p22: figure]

Note that the first two vowel keys are on columns 1 and 2, while the second two vowel keys are on columns 5 and 6.

The simplest fix, if you have liquid flux, is to apply flux to the bad joint or joints, then re-heat the joint with your soldering iron. If you don't have flux, it is best to remove as much of the solder on the joint as possible using solder wick or a desoldering tool, then reapply fresh solder to the joint. Be sure to check both the bottom and top solder joints on the Teensy module.

If some key switch or switches don't work and the issues don't appear to be correlated, then the most likely problem is a cold joint on the diode that is adjacent to each problem key switch. As mentioned previously, try to repair the problem by applying flux to the diode joints and then reheating the solder. Alternatively, remove the solder with solder wick or a desoldering tool and resolder the joints.

It is unlikely but it is also possible that you could have a bad diode, and you could try replacing it. If you have a multimeter, you can verify that a diode is working by selecting the continuity/diode checking function on your meter. The meter should show a voltage drop of about 0.6 V with the black lead on the cathode (black band) and the red lead on the anode. With the leads swapped, the meter should show no connection. If the cathode is not on the left, remove it and resolder it in the correct orientation.

3.

If the LED doesn't light, no matter what position the brightness rotary switch is in, then it is most likely that the LED has been installed backwards or it is burned out. (It is also possible that the brightness rotary switch isn't working at all. See troubleshooting tip 5, below.)

If you have a multimeter, you can verify that a LED is working by selecting the continuity/diode checking function on your meter. The meter should show a voltage drop of about 1.8 V with the black lead on the cathode and the red lead on the anode. With the leads swapped, the meter should show no connection. If the cathode is not on the left, then the LED has been installed backwards; if

4.

so, remove it and resolder it in the correct orientation.
It is also possible that you have a cold solder joint on the LED, the resistor, or the Ground or LED pins on the Teensy module. The simplest fix, if you have liquid flux, is to apply flux to the bad joint or joints, then re-heat each joint with your soldering iron. If you don't have flux, it is best to remove as much of the solder on the joints as possible, using solder wick or a desoldering tool, then reapply fresh solder to the joints.
If neither of the rotary switches is working at all, then the problem is most likely a bad solder joint on the "Option Row" pin of the Teensy module. See troubleshooting tip 2 above for further details.

5.

If one or both rotary switches are not operating correctly, then the problem is most likely a bad solder joint on either the rotary switches or their associated diodes. Diodes D33, D34 and D35 are associated with the protocol switch (SW35 or SW37). Diodes D38, D39 and D40 are associated with brightness switch (SW36 or SW38). See troubleshooting tip 3 above for further details.

6.

If the Arduino software fails to build the Stenokey firmware, it is most likely an incompatibility that has arisen between the Arduino or Teensyduino libraries and the Stenokey firmware. You can get help for the Arduino libraries on the Arduino forum. You can get help for the Teensyduino libraries at PJRC. You can also post an issue to the Stenokey project on Github.

As an alternative to building the Stenokey firmware from scratch, you can load the pre-built firmware instead. The pre-built firmware is in the Firmware sub-directory of the Stenokey distribution in the file StenoFW.ino.hex. To program the Teensy, open the Teensy download program and select "Open HEX File" from the program's File menu. Open the above mentioned hex file to load it into the Teensy program. Press the reset button on the Teensy to program it.

7.

If shorting one key switch causes the micro controller to show two or more key presses at the same time, the problem is most likely a solder bridge on the Teensy module. Carefully check the pins on both the top and bottom of the Teensy to make sure that excess solder isn't connecting any of the pins together. If there is excess solder, remove it with solder wick or a desoldering tool. If you remove too much solder, resolder the affected joints, but apply solder sparingly.

8.

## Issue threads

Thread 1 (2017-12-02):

Consider another name for the Stenokey

morinted, 2017-12-02:
Hey there,

Mirabai pointed out your project on the Plover Discord and I think we're pretty excited about it, it's looking like an awesome low-cost entry into the steno world for DIYers.

I want to suggest considering changing to a more unique name. As a community we're getting into an issue now where new community members get confused by the Stenoboard, Stenomod, Stenosaurus, and other similarly named projects. I think the Stenokey, being a homophone to "steno key" will suffer the same fate.

The one machine in our ecosystem that doesn't have this problem is the SOFT/HRUF (soft love) which is so far out of this world that it's hard to forget.

I think it could be reasonable to consider another name for the Stenokey in order to help it stand out amongst the competition.

Brainstorming:

- DIY, 34 keys, court reporting, programming, arduino, resin, printing, stenography, plover, affordable, portable
- ST34 (#STPH is 1234 in Steno, 34 keys)
- Chordbook
- IATB: "It's about time" board.
- Fineboard
- Pocketbrief
- The B100 Steno Machine (below $100)

morinted, 2017-12-02:
Another one: "Stoinky" which would be a phonetic approximation to the raw steno for writing "steno key" in Plover: `STOEUPB/KAOE`.

morinted, 2017-12-05:
I've also just learned that Stenokey is the name of the [Bulgarian chorded input system](http://galleryofshorthand.org/portfolio/1975-stenokey-bulgaria/)

gdwaynewarner, 2018-01-18:
Just posted a link to Mirabai's review on my Facebook wall ... looks like it's getting some serious interest from court reporters!
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

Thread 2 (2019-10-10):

Ground plane for PCB

arunisaac, 2019-10-10:
Very nice project! :-) I'm planning to build a stenokey for myself. I looked at the PCB and there seems to be no ground plane on the PCB. Isn't this bad for noise performance? Besides, without a ground plane, a lot of copper gets wasted during etching.

Khalinda, 2019-10-10:
Thanks Arunisaac,

The board is low speed and it's deliberately 2 layer to minimize cost so no ground plane.  The cost differential for a 4 layer board at my board house of choice may not be as large as it was 3 or 4 years ago, but it still increases the cost of a board of the size used in the Stenokey project by a factor of 2 or 3.  (The differential is as much as 10 to 1 on smaller boards.)

Certainly, a copper pour on each layer is in order.  Kicad was not always as bug free as it is today and copper pours have caused me much grief.  Even with all of the work that has gone into Kicad these last few years, it still requires vigilance to ensure that a copper pour doesn't cause issues with a board design.

mike-ady, 2019-10-10:
Thanks Arunisaac,

The board is low speed and it's deliberately 2 layer to minimize cost so no ground plane.  The cost differential for a 4 layer board at my board house of choice may not be as large as it was 3 or 4 years ago, but it still increases the cost of a board of the size used in the Stenokey project by a factor of 2 or 3.  (The differential is as much as 10 to 1 on smaller boards.)

Certainly, a copper pour on each layer is in order.  Kicad was not always as bug free as it is today and copper pours have caused me much grief.  Even with all of the work that has gone into Kicad these last few years, it still requires vigilance to ensure that a copper pour doesn't cause issues with a board design.

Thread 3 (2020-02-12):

Typo in Case_Print_Files/Readme.md

arunisaac, 2020-02-12:
In the last paragraph under "Stenokey Case Readme", I think it should be "Only one of the case base variants need be printed", not "Only one of the case top variants need be printed". Notice the change from "case top" to "case base".

mike-ady, 2020-02-20:
Thank you Arun Isaac,

You are correct.  I have made the requested change to the "Case_Print_Files\Readme.md" document, though I have not yet updated the repository on GitHub.

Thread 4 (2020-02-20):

Advice on key top sizes

arunisaac, 2020-02-20:
I'm printing key tops for my stenokey and would like some advice on the ergonomics and compatibility of different key top sizes.

Are the standard Narrow ones sufficient, or are the wider WideCenter key tops ergonomically better especially when pressing multiple adjacent keys together? Does the ergonomics relate much to the stubbiness of one's fingers?

Which combination of key top sizes are compatible and which are not? Perhaps some kind of compatibility matrix would help. If I use WideCenterExtended for all my keys, would that be workable?

mike-ady, 2020-02-20:
Hi Arun Isaac,

Maybe someone else can comment, since I am certainly no expert on steno ergonomics or on steno for that matter.  First of all, note that the key tops are held in by friction, so you can easily change keys out if you've printed a few extra "fingers" of keys and want to experiment.

Every steno machine is somewhat different.  What seems to be the style these days would dictate printing only the narrow keys.  (That is what I prefer.)  The early Ward Ireland Stenotype machines had a single very wide paddle for the asterisk key, but other than that, the keys were narrow with equal spacing between keys.  Some more recent machines have the equivalent of Stenokey's "FingerDouble.stl" for the asterisk finger.  Others have had the equivalent of "FingerWideRight.stl" for the asterisk finger.  And still others have had the equivalent of "FingerWideLeft.stl" for the right pinky finger (D & Z keys).  In general all other keys should be of the narrow variety.

As I have mentioned elsewhere, I don't particularly recommend the extended keys.  I designed those more for myself as something to experiment with.

arunisaac, 2020-02-21:
Thank you, I will experiment with a few configurations on those
lines. Maybe, you should add some version of your reply to
Key_Print_Files/Readme.md.

Thank you very much for your time and effort in developing and releasing
stenokey as freedom hardware! Your work is immensely useful to me! :-)

Closed 2020-02-21.

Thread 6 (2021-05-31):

Is There a way to Disable the Number Bar?

gdwaynewarner, 2021-05-31:
This project sounds great, except for the whole "build-it-yourself" issue, but as the title says, is there a way to disable the number bar?

When I was in Theory, I was given the choice to either use the number bar or stroke the numbers phonetically. I opted for the later, and the reason for that was if I use the number bar, I still get a number. Right one? Wrong one? Who knows?

However, if I screw up a stroke for a number, I just get steno, from which I should be able to figure out what number I was trying to write.

While I was using the Splitography, my fingers kept hitting the number bar, and there was no way that I could see to shut it off so my accidental taps didn't interfere with what I was trying to write.

Hence the need to be able to deactivate it.

mike-ady, 2021-05-31:
You could of course remove the key tops from the upper row of key switches.

Another approach would be to cut the copper trace between the Teensy module and the top row of keys.  The particular trace that needs to be cut depends on which side of the PCB the Teensy module is mounted on.  If the module is on the left, a trace on the back of the PCB must be cut.  I have marked a location on the trace that should be cut, in magenta, on the following picture:

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

Note that the picture is flipped right to left, since the PCB is viewed from the back.  If the module is on the right, you can find a location on the front of the board to sever the required trace marked on the following picture.

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

If you've never cut a trace on a PCB before, it may be harder than you think.  You will need a sharp knife, and you will need to scrape through the epoxy solder mask and fully through the  copper trace.  Avoid severing any other traces.

Perhaps the best alternative is to modify the Stenokey firmware.  The attached screen print shows the line in the "readKeys" function that must be changed.  [TMI:  The rows on the keyboard are numbered 0 through 4 (row 4 is actually used to scan the rotary switches at the top of the keyboard).  Row 0 is the row of number keys.  If readKeys doesn't actually read the top row of keys, their key codes won't be transmitted.]

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

In the screen print, I have made a copy of the original line of code and modified that.  I have retained the original line of code, but commented it out, to document the original functionality of the code.

After making the change to the StenoFW.ino file, follow the instructions in the "Stenokey_test.pdf" or "Stenokey_test.md" file to compile and upload the modified firmware to your Stenokey.

gdwaynewarner, 2021-06-01:
Good to know!

I think I have an Exacto knife here somewhere, should the need arise (no Makers close by).

gdwaynewarner, 2023-01-10:
Sticking with my ProCAT Flash, and giving up on the hobby steno keyboards for now.

Closed 2023-01-10.

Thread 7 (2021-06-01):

Key numbers dont align with code

Corallus-Caninus, 2021-06-01:
I am creating a StenoKey. Thanks for the work you have done!

I have noticed that the keys don't map to the correct positions in the code. for instance, in my PCB file switch 34 is [row][col] index [0][10] in Eeschema but is on the bottom row on the PCB.

Example: Switches 1-10 are on the top row (the number bar) but are only assigned to the left hand in Eeschema.

I am reviewing the Software for additional errors as I don't see how the column pins can map to the appropriate mappings in the protocol look up tables if said mappings are based on the schematic and not completely reassigned.

mike-ady, 2021-06-01:
I am not sure what you are seeing.  Switch SW34 is on "ROW3, COL6" on the schematic in EESchema and it is the right-most vowel key at the intersection of traces "ROW3" and "COL6" on the PCB in PCBNew.  The layout used in the firmware is shown on lines 54 - 58 of StenoFW.ino.  The row and column numbering used in the schematic is consistent with the zero based indexing used in C.  (However, one based indexing is used elsewhere--in the documentation in particular.)

The code actually does work with the PCB.  In fact, "I am typing these words" with a Stenokey and Plover software.

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

Corallus-Caninus, 2021-06-05:
ahh man I managed to remap all the symbols. I have reworked the schematic with a Pico and a single layer PCB and no diodes/passive components using firmware driver configuration only but I must have messed up the numbering somewhere along the way (I just finished editing every value one at a time :/ ) I checked with a fresh clone and it is correct. Ill fork my mod once I got it working thanks for the awesome project!

Closed 2021-06-05.

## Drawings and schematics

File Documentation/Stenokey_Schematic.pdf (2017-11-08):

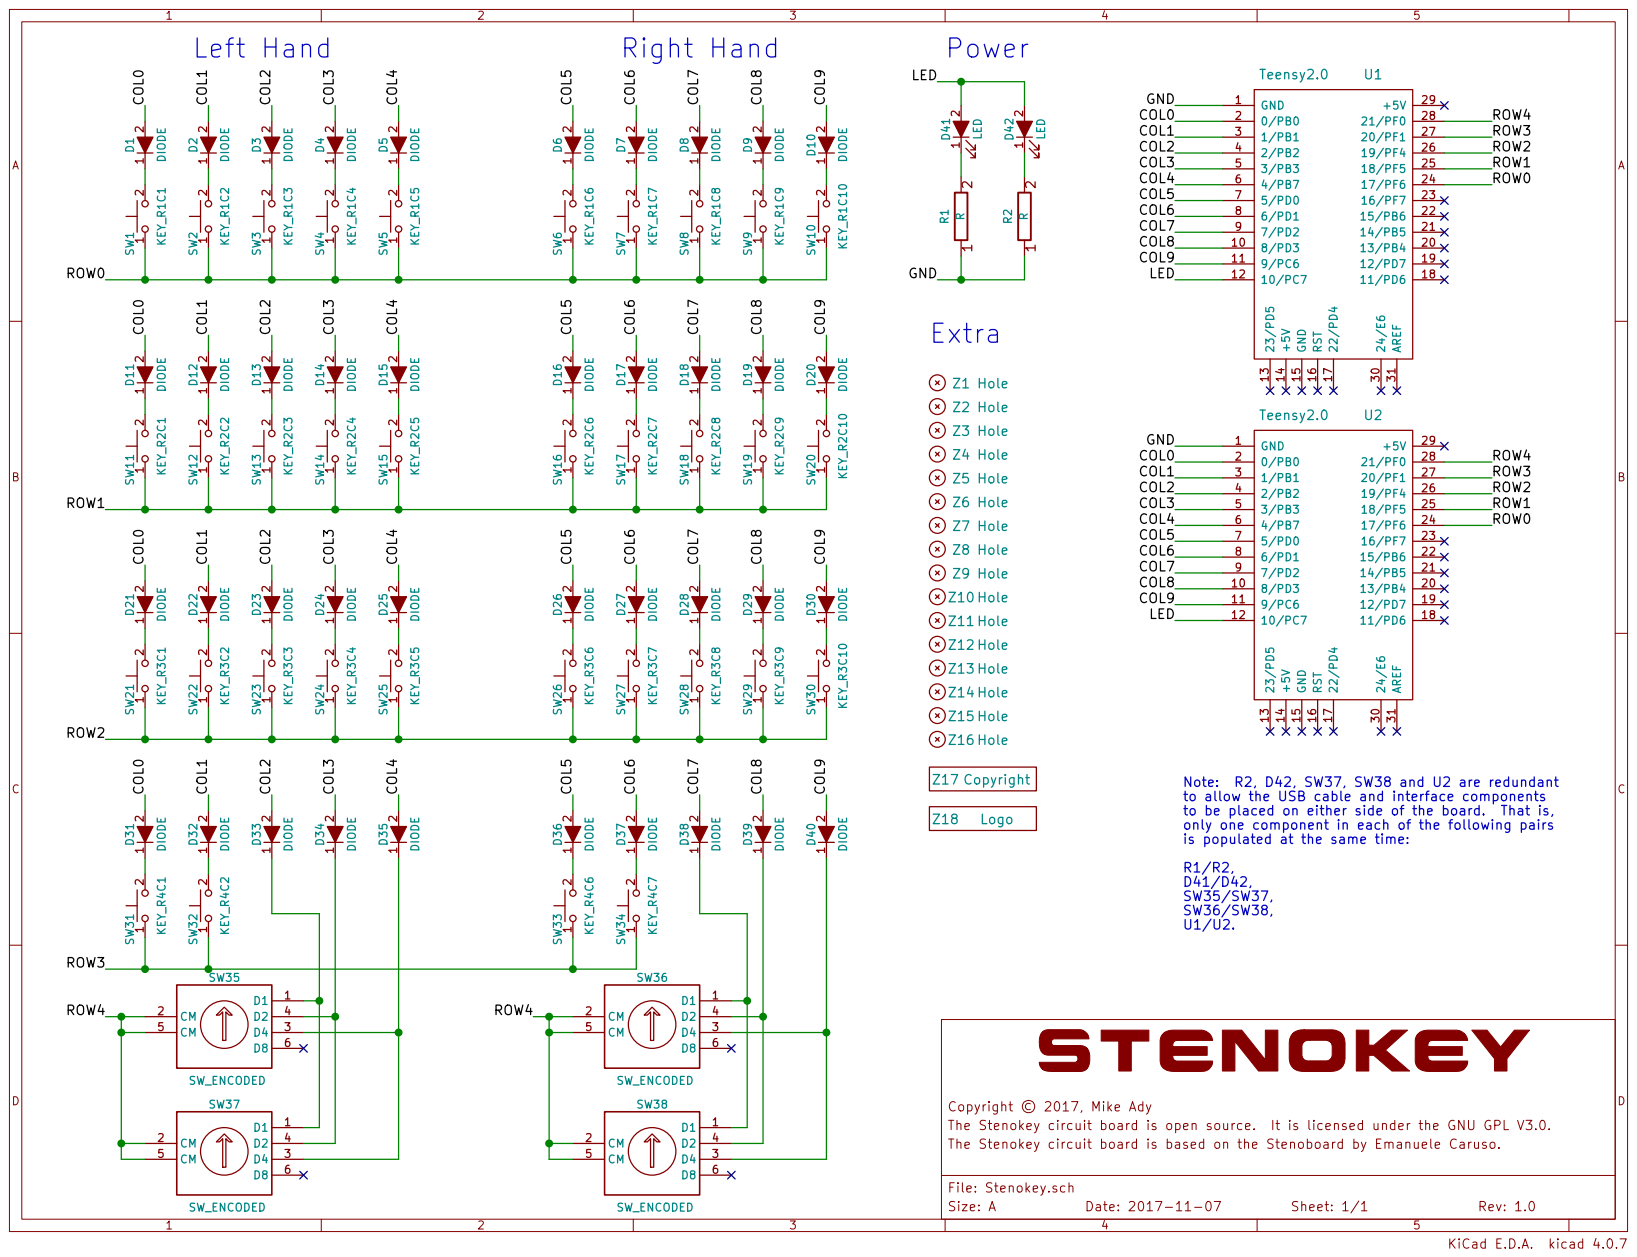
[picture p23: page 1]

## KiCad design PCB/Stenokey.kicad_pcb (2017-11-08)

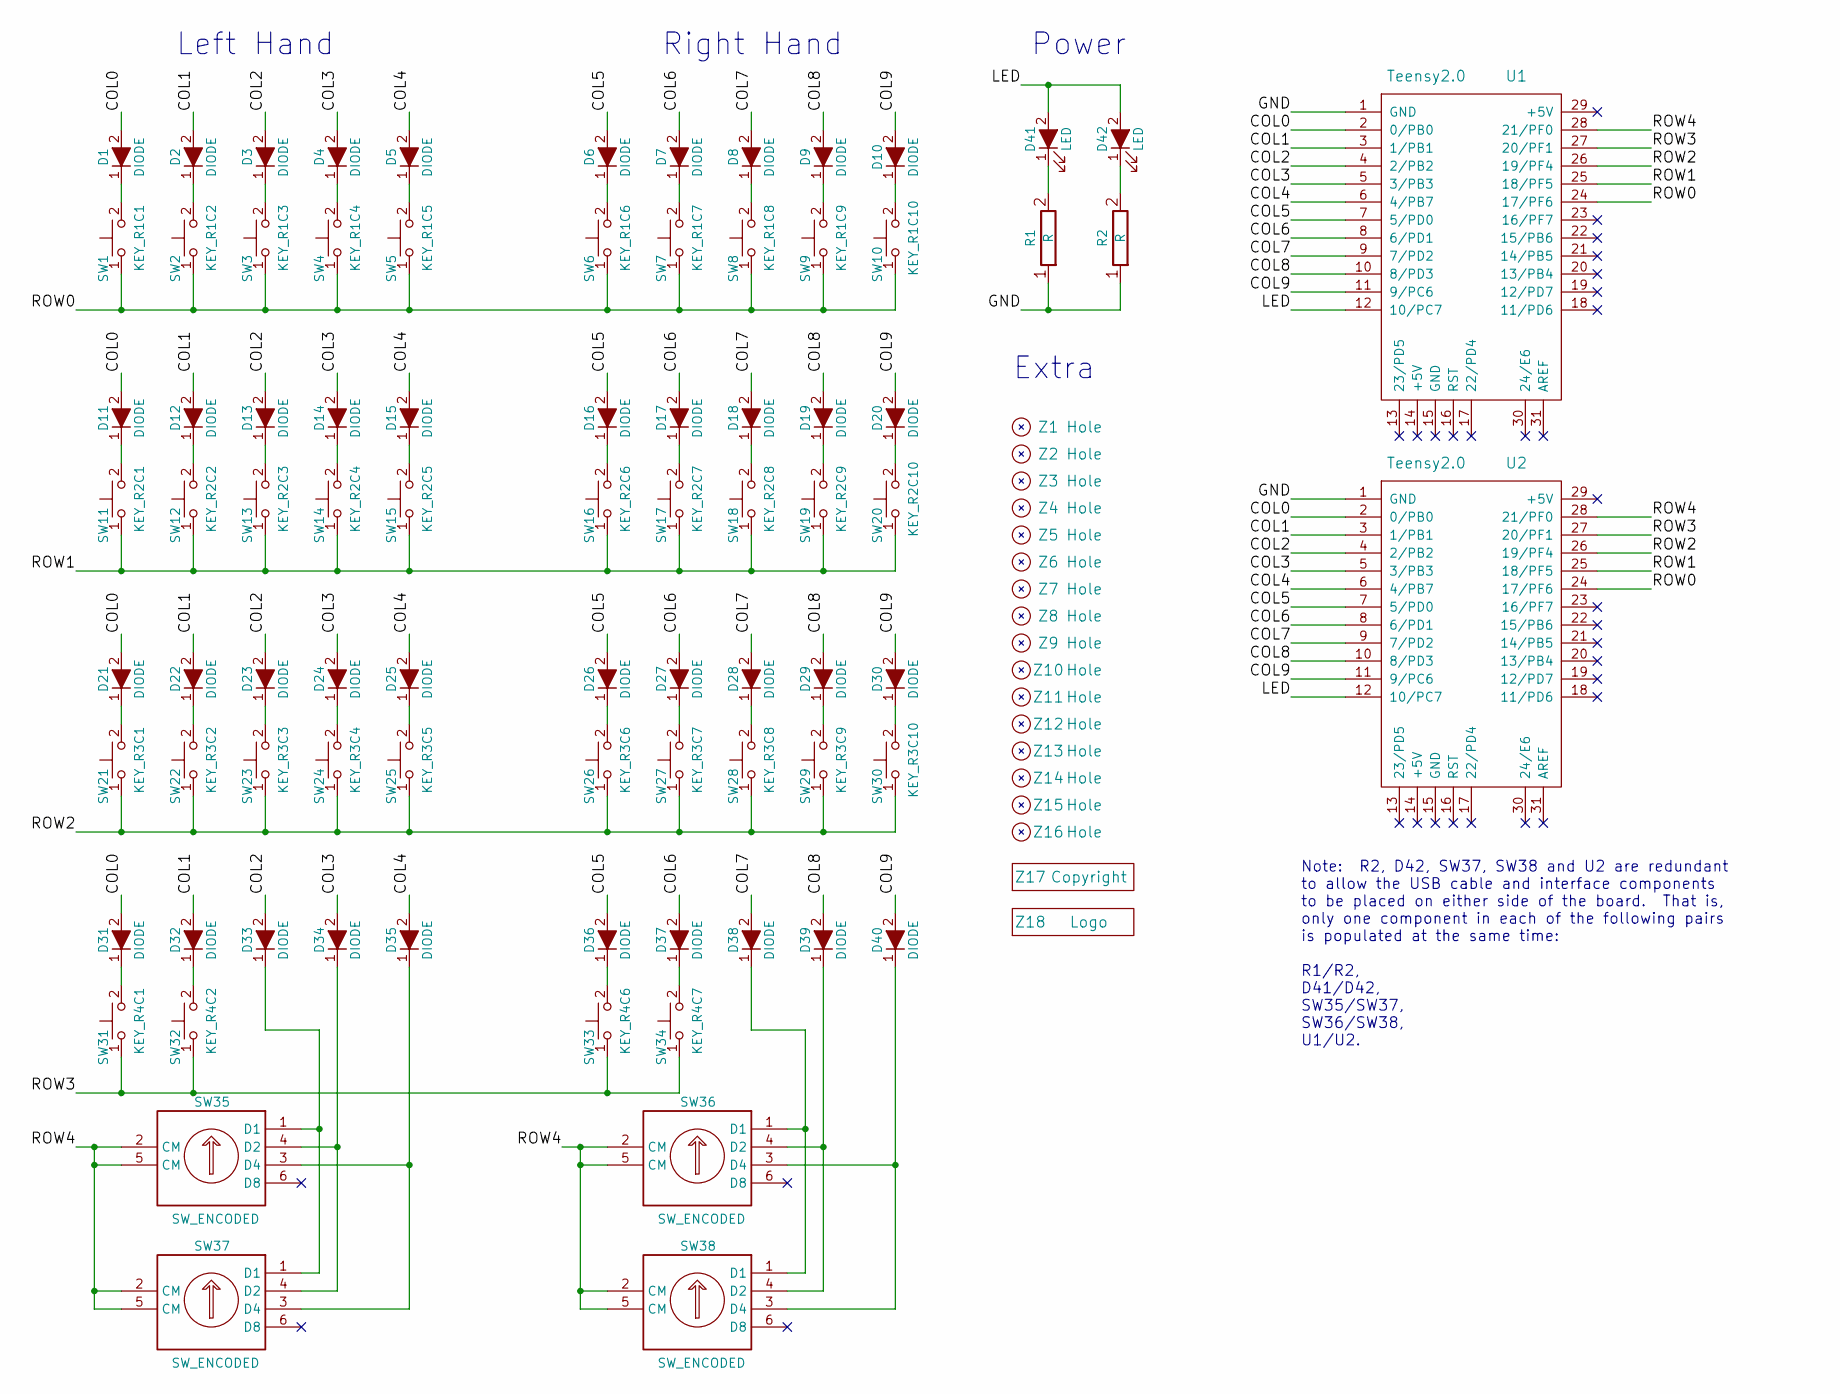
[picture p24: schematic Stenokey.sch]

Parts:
D1, D2, D3, D4, D5, D6, D7, D8, D9, D10, D11, D12, D13, D14, D15, D16, D17, D18, D19, D20, D21, D22, D23, D24, D25, D26, D27, D28, D29, D30, D31, D32, D33, D34, D35, D36, D37, D38, D39, D40: DIODE; D4x2
D41, D42: LED; LED5X2.5
R1, R2: R; R4x2
SW1: KEY_R1C1; SW_Matias_Quiet
SW2: KEY_R1C2; SW_Matias_Quiet
SW3: KEY_R1C3; SW_Matias_Quiet
SW4: KEY_R1C4; SW_Matias_Quiet
SW5: KEY_R1C5; SW_Matias_Quiet
SW6: KEY_R1C6; SW_Matias_Quiet
SW7: KEY_R1C7; SW_Matias_Quiet
SW8: KEY_R1C8; SW_Matias_Quiet
SW9: KEY_R1C9; SW_Matias_Quiet
SW10: KEY_R1C10; SW_Matias_Quiet
SW11: KEY_R2C1; SW_Matias_Quiet
SW12: KEY_R2C2; SW_Matias_Quiet
SW13: KEY_R2C3; SW_Matias_Quiet
SW14: KEY_R2C4; SW_Matias_Quiet
SW15: KEY_R2C5; SW_Matias_Quiet
SW16: KEY_R2C6; SW_Matias_Quiet
SW17: KEY_R2C7; SW_Matias_Quiet
SW18: KEY_R2C8; SW_Matias_Quiet
SW19: KEY_R2C9; SW_Matias_Quiet
SW20: KEY_R2C10; SW_Matias_Quiet
SW21: KEY_R3C1; SW_Matias_Quiet
SW22: KEY_R3C2; SW_Matias_Quiet
SW23: KEY_R3C3; SW_Matias_Quiet
SW24: KEY_R3C4; SW_Matias_Quiet
SW25: KEY_R3C5; SW_Matias_Quiet
SW26: KEY_R3C6; SW_Matias_Quiet
SW27: KEY_R3C7; SW_Matias_Quiet
SW28: KEY_R3C8; SW_Matias_Quiet
SW29: KEY_R3C9; SW_Matias_Quiet
SW30: KEY_R3C10; SW_Matias_Quiet
SW31: KEY_R4C1; SW_Matias_Quiet
SW32: KEY_R4C2; SW_Matias_Quiet
SW33: KEY_R4C6; SW_Matias_Quiet
SW34: KEY_R4C7; SW_Matias_Quiet
SW35, SW36, SW37, SW38: SW_ENCODED; DIP6
U1, U2: Teensy2.0
Z1, Z2, Z3, Z4, Z5, Z6, Z7, Z8, Z9, Z10, Z11, Z12, Z13, Z14, Z15, Z16: Hole; HOLE_600800
Z17: Copyright
Z18: Logo; StenoKeyLogo

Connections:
/COL0: D1.2 (A), D11.2 (A), D21.2 (A), D31.2 (A), U1.2 (0/PB0), U2.2 (0/PB0)
/COL1: D2.2 (A), D12.2 (A), D22.2 (A), D32.2 (A), U1.3 (1/PB1), U2.3 (1/PB1)
/COL2: D3.2 (A), D13.2 (A), D23.2 (A), D33.2 (A), U1.4 (2/PB2), U2.4 (2/PB2)
/COL3: D4.2 (A), D14.2 (A), D24.2 (A), D34.2 (A), U1.5 (3/PB3), U2.5 (3/PB3)
/COL4: D5.2 (A), D15.2 (A), D25.2 (A), D35.2 (A), U1.6 (4/PB7), U2.6 (4/PB7)
/COL5: D6.2 (A), D16.2 (A), D26.2 (A), D36.2 (A), U1.7 (5/PD0), U2.7 (5/PD0)
/COL6: D7.2 (A), D17.2 (A), D27.2 (A), D37.2 (A), U1.8 (6/PD1), U2.8 (6/PD1)
/COL7: D8.2 (A), D18.2 (A), D28.2 (A), D38.2 (A), U1.9 (7/PD2), U2.9 (7/PD2)
/COL8: D9.2 (A), D19.2 (A), D29.2 (A), D39.2 (A), U1.10 (8/PD3), U2.10 (8/PD3)
/COL9: D10.2 (A), D20.2 (A), D30.2 (A), D40.2 (A), U1.11 (9/PC6), U2.11 (9/PC6)
/GND: R1.1, R2.1, U1.1 (GND), U2.1 (GND)
/LED: D41.2 (A), D42.2 (A), U1.12 (10/PC7), U2.12 (10/PC7)
/ROW0: SW1.1, SW2.1, SW3.1, SW4.1, SW5.1, SW6.1, SW7.1, SW8.1, SW9.1, SW10.1, U1.24 (17/PF6), U2.24 (17/PF6)
/ROW1: SW11.1, SW12.1, SW13.1, SW14.1, SW15.1, SW16.1, SW17.1, SW18.1, SW19.1, SW20.1, U1.25 (18/PF5), U2.25 (18/PF5)
/ROW2: SW21.1, SW22.1, SW23.1, SW24.1, SW25.1, SW26.1, SW27.1, SW28.1, SW29.1, SW30.1, U1.26 (19/PF4), U2.26 (19/PF4)
/ROW3: SW31.1, SW32.1, SW33.1, SW34.1, U1.27 (20/PF1), U2.27 (20/PF1)
/ROW4: SW35.2 (CM), SW35.5 (CM), SW36.2 (CM), SW36.5 (CM), SW37.2 (CM), SW37.5 (CM), SW38.2 (CM), SW38.5 (CM), U1.28 (21/PF0), U2.28 (21/PF0)
unnamed: D1.1 (K), SW1.2
unnamed: D2.1 (K), SW2.2
unnamed: D3.1 (K), SW3.2
unnamed: D4.1 (K), SW4.2
unnamed: D5.1 (K), SW5.2
unnamed: D6.1 (K), SW6.2
unnamed: D7.1 (K), SW7.2
unnamed: D8.1 (K), SW8.2
unnamed: D9.1 (K), SW9.2
unnamed: D10.1 (K), SW10.2
unnamed: D11.1 (K), SW11.2
unnamed: D12.1 (K), SW12.2
unnamed: D13.1 (K), SW13.2
unnamed: D14.1 (K), SW14.2
unnamed: D15.1 (K), SW15.2
unnamed: D16.1 (K), SW16.2
unnamed: D17.1 (K), SW17.2
unnamed: D18.1 (K), SW18.2
unnamed: D19.1 (K), SW19.2
unnamed: D20.1 (K), SW20.2
unnamed: D21.1 (K), SW21.2
unnamed: D22.1 (K), SW22.2
unnamed: D23.1 (K), SW23.2
unnamed: D24.1 (K), SW24.2
unnamed: D25.1 (K), SW25.2
unnamed: D26.1 (K), SW26.2
unnamed: D27.1 (K), SW27.2
unnamed: D28.1 (K), SW28.2
unnamed: D29.1 (K), SW29.2
unnamed: D30.1 (K), SW30.2
unnamed: D31.1 (K), SW31.2
unnamed: D32.1 (K), SW32.2
unnamed: D33.1 (K), SW35.1 (D1), SW37.1 (D1)
unnamed: D34.1 (K), SW35.4 (D2), SW37.4 (D2)
unnamed: D35.1 (K), SW35.3 (D4), SW37.3 (D4)
unnamed: D36.1 (K), SW33.2
unnamed: D37.1 (K), SW34.2
unnamed: D38.1 (K), SW36.1 (D1), SW38.1 (D1)
unnamed: D39.1 (K), SW36.4 (D2), SW38.4 (D2)
unnamed: D40.1 (K), SW36.3 (D4), SW38.3 (D4)
unnamed: D41.1 (K), R1.2
unnamed: D42.1 (K), R2.2

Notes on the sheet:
Left Hand
Right Hand
Power
Note: R2, D42, SW37, SW38 and U2 are redundant to allow the USB cable and interface components to be placed on either side of the board. That is, only one component in each of the following pairs is populated at the same time: R1/R2, D41/D42, SW35/SW37, SW36/SW38, U1/U2.
Extra

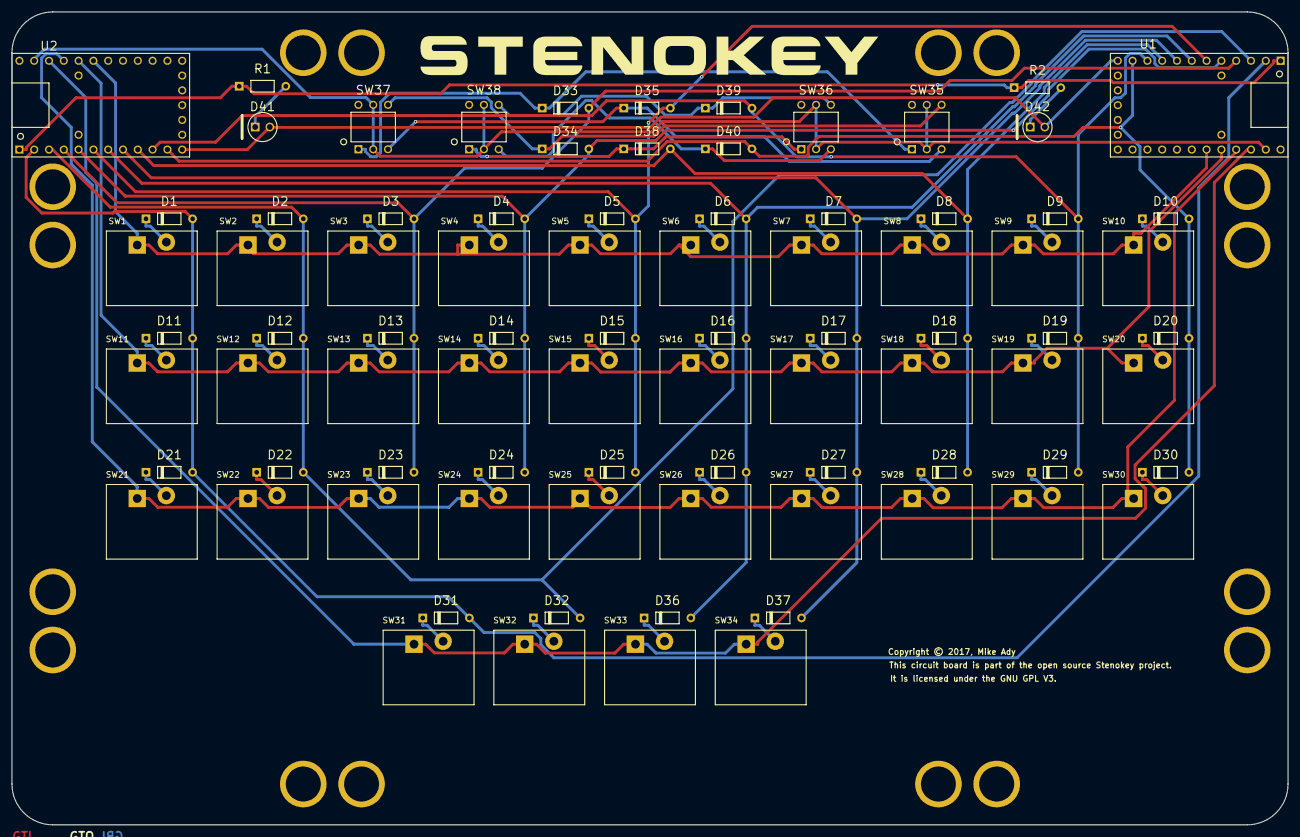
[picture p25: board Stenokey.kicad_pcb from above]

Board: 2 copper layers, 219.0 x 139.5 mm, 102 parts (0 on the bottom side), 59 nets.

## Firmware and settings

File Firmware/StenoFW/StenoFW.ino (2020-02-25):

/**
 * StenoFW is the Stenokey firmware.
 *
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
 * Copyright 2014 Emanuele Caruso.  See LICENSE.txt for details.
 * Portions Copyright 2017, Michael Ady.
 * Portions of Gemini encoding Copyright 2011, Joshua Lifton (OpenStenoProject).
 * Portions of Procat encoding Copyright 2016, Ted Morin (OpenStenoProject).
 */

// Stenokey modification log:

// 1.  ROWS and COLS were changed to reflect the physical board layout which 
// is 4 rows of 10 keys.
// 2.  rowPins and colPins were modified to reflect the pin assignments
// on the Teensy 2.0 board.
// 3.  In lieu of the function keys on the Stenoboard, the StenoKey has two 
// BCD encoded rotary switches.  Switch 1 is used to select the protocol, 
// while switch 2 is used to vary the power LED brightness.  These switches
// are wired to an extra "row", to simplify decoding.  The function key 
// handling routines were replaced with a single options handling routine.
// 4.  A parenthesis error in the debounce logic was corrected.
// 5.  The NKRO, Gemini and TxBolt protocol functions were simplified.
// 6.  The Procat and Diagnostic protocols were added.

#define ROWS			4
#define COLS			10

// Protocols

#define DIAGNOSTIC		0
#define NKRO			1
#define GEMINI			2
#define TXBOLT			3
#define PROCAT			4
#define MAX_PROTOCOL	5				// one more than last protocol

// The following matrix is for reference only.
// It shows which rows and columns the keys are wired to.
// ' ' marks an empty location.
 
//char keys[ROWS][COLS] = {
//	{'#', '#', '#', '#', '#', '#', '#', '#', '#', '#'},	// upper consonant row
//	{'S', 'T', 'P', 'H', '*', 'F', 'P', 'L', 'T', 'D'},	// middle consonant row
//	{'S', 'K', 'W', 'R', '*', 'R', 'B', 'G', 'S', 'Z'},	// lower consonant row
//	{'A', 'O', ' ', ' ', ' ', 'E', 'U', ' ', ' ', ' '}	// vowel row
//};

// Configuration variables

int rowPins[ROWS+1] = {17, 18, 19, 20, 21};
int colPins[COLS] = {0, 1, 2, 3, 4, 5, 6, 7, 8, 9};
int ledPin = 10;
unsigned long debounceMillis = 20;

// Keyboard state variables

boolean isStrokeInProgress = false;
boolean currentChord[ROWS][COLS];
boolean currentKeyReadings[ROWS][COLS];			// key input buffer
boolean debouncingKeys[ROWS][COLS];
unsigned long debouncingMicros[ROWS][COLS];

// Option states

byte Protocol;
byte Brightness;
byte BrightnessLevels[8]=			// uniform CIE "lightness" levels
{
	0, 5, 14, 33, 64, 109, 172, 255
};

// Function prototypes

void Options();
void sendChord();


// This is called when the keyboard is connected

void setup()
{
  Keyboard.begin();
  Serial.begin(9600);
  for (int i = 0; i < COLS; i++)
    pinMode(colPins[i], INPUT_PULLUP);
  for (int i = 0; i < ROWS+1; i++)
  {
    pinMode(rowPins[i], OUTPUT);
    digitalWrite(rowPins[i], HIGH);
  }
  pinMode(ledPin, OUTPUT);
  clearBooleanMatrices();
}

// Read key states and handle all chord events

void loop()
{
  // Handle options switches first
  
  Options();

  readKeys();
  
  boolean isAnyKeyPressed = true;
  
  // If stroke is not in progress, check debouncing keys
  
  if (!isStrokeInProgress)
  {
    checkAlreadyDebouncingKeys();
    if (!isStrokeInProgress)
		checkNewDebouncingKeys();
  }
  
  // If any key was pressed, record all pressed keys
  
  if (isStrokeInProgress)
  {
    isAnyKeyPressed = recordCurrentKeys();
  }
  
  // If all keys have been released, send the chord and reset the global state
  
  if (!isAnyKeyPressed)
  {
    sendChord();
    clearBooleanMatrices();
    isStrokeInProgress = false;
  }
}

// Read all keys

void readKeys()
{
  for (int i = 0; i < ROWS; i++)
  {
    digitalWrite(rowPins[i], LOW);
    for (int j = 0; j < COLS; j++)
      currentKeyReadings[i][j] = digitalRead(colPins[j]) == LOW ? true : false;
    digitalWrite(rowPins[i], HIGH);
  }
}

// Check already debouncing keys. If a key debounces, start chord recording.

void checkAlreadyDebouncingKeys()
{
  for (int i = 0; i < ROWS; i++)
  {
    for (int j = 0; j < COLS; j++)
	{
      if (debouncingKeys[i][j] == true && currentKeyReadings[i][j] == false)
	  {
        debouncingKeys[i][j] = false;
        continue;
      }
      if (debouncingKeys[i][j] == true && (micros() - debouncingMicros[i][j]) / 1000 > debounceMillis)
	  {
        isStrokeInProgress = true;
        currentChord[i][j] = true;
        return;
      }
    }
  }
}

// If a key is pressed, add it to debouncing keys and record the time

void checkNewDebouncingKeys()
{
  for (int i = 0; i < ROWS; i++)
  {
    for (int j = 0; j < COLS; j++)
	{
      if (currentKeyReadings[i][j] == true && debouncingKeys[i][j] == false)
	  {
        debouncingKeys[i][j] = true;
        debouncingMicros[i][j] = micros();
      }
    }
  }
}

// Record all pressed keys into current chord. Return false if no key is currently pressed

boolean recordCurrentKeys()
{
  boolean isAnyKeyPressed = false;
  
  for (int i = 0; i < ROWS; i++)
  {
    for (int j = 0; j < COLS; j++)
	{
      if (currentKeyReadings[i][j] == true)
	  {
        currentChord[i][j] = true;
        isAnyKeyPressed = true;
      }
    }
  }
  return isAnyKeyPressed;
}

// Set all values of all boolean Matrices to false

void clearBooleanMatrices()
{
  clearBooleanMatrix(currentChord, false);
  clearBooleanMatrix(currentKeyReadings, false);
  clearBooleanMatrix(debouncingKeys, false);
}

// Set all values of the passed matrix to the given value

void clearBooleanMatrix(boolean booleanMatrix[][COLS], boolean value)
{
  for (int i = 0; i < ROWS; i++)
  {
    for (int j = 0; j < COLS; j++)
	{
      booleanMatrix[i][j] = value;
    }
  }
}

// Diagnostic Protocol

// Each key pressed results in 3 characters being sent, which consists of
// the row number, followed by the column number and a blank.  The chord
// is terminated with a newline.

void sendChordDiagnostic()
{
  int k = 0;							// chord byte index
  char chordBytes[34*3+1];				// chord buffer
  
  // Fill in chord buffer
  
  for (int i = 0; i < ROWS; i++)
    for (int j = 0; j < COLS; j++)
      if (currentChord[i][j])
	  {
        chordBytes[k++] = '1'+i;		// row
        if(j==9)						// column
          chordBytes[k++] = 'A';
        else
          chordBytes[k++] = '1'+j;
        chordBytes[k++] = ' ';
      }
  chordBytes[k-1] = '\n';				// terminate chord
	  
  // Send the packet
 
  for (int i = 0; i < k; i++)
    Serial.write(chordBytes[i]);
}
 
// NKRO Keyboard Emulation

#define ISNUM(x)	((x)>='0'&&(x)<='9')

void sendChordNkro()
{
  // US keyboard mapping
  
  static const char NkroMapping[ROWS][COLS] =
  {
    {'1', '2', '3', '4', '5', '6', '7', '8', '9', '0'},		// upper row
    {'q', 'w', 'e', 'r', 't', 'u', 'i', 'o', 'p', '['},		// middle row
    {'a', 's', 'd', 'f', 'g', 'j', 'k', 'l', ';', '\''},	// lower row
    {'c', 'v',  0,   0,   0,  'n', 'm',  0,   0,   0}		// vowel row
 };

  int keyCounter = 0;							// chord index
  char NkroKeys[ROWS * COLS];					// chord buffer
//  int k;										// loop index
  
  // Calculate NKRO keys array using NkroMapping[][]
  // Do not include nulls in the chord, to simplify processing below.
  // Due to a Plover quirk, do not include more than one number key in the chord.
  
  for (int i = 0; i < ROWS; i++)
    for (int j = 0; j < COLS; j++)
      if (currentChord[i][j])
	  {
//        for (k = 0; k < keyCounter; k++)
//        {
//        	if (ISNUM(NkroKeys[k]) && ISNUM(NkroMapping[i][j]))
//                break;
//        }
//        if (k != keyCounter)
//        	continue;
        NkroKeys[keyCounter] = NkroMapping[i][j];
        if(NkroKeys[keyCounter])				// if mapped key
          keyCounter++;
      }
	  
  // Emulate keyboard key presses
  // Because the Arduino USB library adheres to the version 1 USB spec, it
  // only supports 6KRO.  To get around this, the first character is pressed,
  // then each subsequent character is pressed and released and finally all
  // characters are released.  Plover knows to reassemble this sequence into
  // a single chord.
  
  for (int i = 0; i < keyCounter; i++)
  {
    Keyboard.press(NkroKeys[i]);
    if(i)
	  Keyboard.release(NkroKeys[i]);
  }
  Keyboard.releaseAll();
}
 
// Gemini Protocol

// The Gemini protocol sends a packet of 6 bytes.  The first byte
// has its sign bit set, while the remaining bytes do not.

// Following table is from OpenStenoProject.  Entries are in 
// msb to lsb order.

// "Fn",  "#1",  "#2", "#3", "#4", "#5",   "#6",
// "S1-", "S2-", "T-", "K-", "P-", "W-",   "H-",
// "R-",  "A-",  "O-", "*1", "*2", "res1", "res2",
// "pwr", "*3",  "*4", "-E", "-U", "-F",   "-R",
// "-P",  "-B",  "-L", "-G", "-T", "-S",   "-D",
// "#7",  "#8",  "#9", "#A", "#B", "#C",   "-Z"

#define GEMINI_BYTES	6

void sendChordGemini()
{
	static const byte GeminiBits[ROWS][COLS]=
	{
		{0x01, 0x01, 0x01, 0x01, 0x01, 0x01, 0x01, 0x01, 0x01, 0x01},
		{0x40, 0x10, 0x04, 0x01, 0x08, 0x02, 0x40, 0x10, 0x04, 0x01},
		{0x40, 0x08, 0x02, 0x40, 0x08, 0x01, 0x20, 0x08, 0x02, 0x01},
		{0x20, 0x10, 0x00, 0x00, 0x00, 0x08, 0x04, 0x00, 0x00, 0x00}
	};
	static const byte GeminiBytes[ROWS][COLS]=
	{
		{0, 0, 0, 0, 0, 0, 0, 0, 0, 0},
		{1, 1, 1, 1, 2, 3, 4, 4, 4, 4},
		{1, 1, 1, 2, 2, 3, 4, 4, 4, 5},
		{2, 2, 0, 0, 0, 3, 3, 0, 0, 0}
	};		   
	
  // Initialize chord bytes
  
  byte chordBytes[GEMINI_BYTES] = {0x80, 0x00, 0x00, 0x00, 0x00, 0x00};
  
  // Calculate Gemini bytes using GeminiBits and GeminiBytes
  
  for (int i = 0; i < ROWS; i++)
    for (int j = 0; j < COLS; j++)
      if (currentChord[i][j])
        chordBytes[GeminiBytes[i][j]]|=GeminiBits[i][j];
 
  // Send the packet
 
  for (int i = 0; i < GEMINI_BYTES; i++)
    Serial.write(chordBytes[i]);
}

// TX Bolt Protocol

// TX Bolt uses a variable length packet. Only those bytes that have active
// keys are sent. The header bits indicate which keys are being sent. They
// must be sent in order.  A zero byte is sent after every packet.

// 00XXXXXX 01XXXXXX 10XXXXXX 110XXXXX
//   HWPKTS   UE*OAR   GLBPRF    #ZDST

#define TXBOLT_BYTES	4

void sendChordTxBolt()
{
	static const byte TxBoltBits[ROWS][COLS]=
	{
		{0x10, 0x10, 0x10, 0x10, 0x10, 0x10, 0x10, 0x10, 0x10, 0x10}, 
		{0x01, 0x02, 0x08, 0x20, 0x08, 0x01, 0x04, 0x10, 0x01, 0x04},
		{0x01, 0x04, 0x10, 0x01, 0x08, 0x02, 0x08, 0x20, 0x02, 0x08},
		{0x02, 0x04, 0x00, 0x00, 0x00, 0x10, 0x20, 0x00, 0x00, 0x00}
	};
	static const byte TxBoltBytes[ROWS][COLS]=
	{
		{3, 3, 3, 3, 3, 3, 3, 3, 3, 3},
		{0, 0, 0, 0, 1, 2, 2, 2, 3, 3},
		{0, 0, 0, 1, 1, 2, 2, 2, 3, 3},
		{1, 1, 0, 0, 0, 1, 1, 0, 0, 0}
	};

  byte chordBytes[TXBOLT_BYTES] = {0x00, 0x40, 0x80, 0xC0};
  
  // Calculate TxBolt bytes using TxBoltBits and TxBoltBytes
  
  for (int i = 0; i < ROWS; i++)
    for (int j = 0; j < COLS; j++)
      if (currentChord[i][j])
        chordBytes[TxBoltBytes[i][j]]|=TxBoltBits[i][j];
 
  // Send the packet
 
  for (int i = 0; i < TXBOLT_BYTES; i++)
    if(chordBytes[i]&0x3F)
	  Serial.write(chordBytes[i]);
  Serial.write((byte)0);						// send terminating byte
}

// Send current chord over serial using the Procat protocol. 

// The Procat protocol sends a packet of 4 bytes.  The first three
// bytes are bit encoded.  The first byte has its sign bit cleared.  
// The last byte has a value of 0xFF.

// The following table is from the OpenStenoProject.  Entries are in 
// msb to lsb order.

// "@",  "#",  "S-", "T-", "K-", "P-", "W-", "H-",
// "R-", "A-", "O-", "*",  "-E", "-U", "-F", "-R",
// "-P", "-B", "-L", "-G", "-T", "-S", "-D", "-Z"

#define PROCAT_BYTES	3

void sendChordProcat()
{
	static const byte ProcatBits[ROWS][COLS]=
	{
		{0x40, 0x40, 0x40, 0x40, 0x40, 0x40, 0x40, 0x40, 0x40, 0x40},
		{0x20, 0x10, 0x04, 0x01, 0x10, 0x02, 0x80, 0x20, 0x08, 0x02},
		{0x20, 0x08, 0x02, 0x80, 0x10, 0x01, 0x40, 0x10, 0x04, 0x01},
		{0x40, 0x20, 0x00, 0x00, 0x00, 0x08, 0x04, 0x00, 0x00, 0x00}
	};
	static const byte ProcatBytes[ROWS][COLS]=
	{
		{0, 0, 0, 0, 0, 0, 0, 0, 0, 0},
		{0, 0, 0, 0, 1, 1, 2, 2, 2, 2},
		{0, 0, 0, 1, 1, 1, 2, 2, 2, 2},
		{1, 1, 0, 0, 0, 1, 1, 0, 0, 0}
	};		   

  // Initialize chord bytes
  
  byte chordBytes[PROCAT_BYTES] = {0x00, 0x00, 0x00};
  
  // Calculate Procat bytes using ProcatBits and ProcatBytes
  
  for (int i = 0; i < ROWS; i++)
    for (int j = 0; j < COLS; j++)
      if (currentChord[i][j])
        chordBytes[ProcatBytes[i][j]]|=ProcatBits[i][j];
 
  // Send the packet
 
  for (int i = 0; i < PROCAT_BYTES; i++)
    Serial.write(chordBytes[i]);
  Serial.write(0xFF);
}


// Send the chord using the current protocol. 

void sendChord()
{
  if (Protocol == NKRO)
    sendChordNkro();
  if (Protocol == GEMINI)
    sendChordGemini();
  else if (Protocol == TXBOLT)
    sendChordTxBolt();
  else if (Protocol == PROCAT)
    sendChordProcat();
  else
    sendChordDiagnostic();				// default
}
/*
// Blink (turn off the LED) the specified number of times

// A count of 0 will cause the LED to turn off for a full second.

void Blink
(
	byte count							// number of times to blink power LED
)
{
	int i;								// loop index
	
	if(!count)
	{
		analogWrite(ledPin,0);
		delay(1000);
		analogWrite(ledPin,BrightnessLevels[Brightness]);
	}
	else
	{
		for(i=0;i<count;i++)
		{
			delay(250);
			analogWrite(ledPin,0);
			delay(250);
			analogWrite(ledPin,BrightnessLevels[Brightness]);
		}		
	}
}
*/
// Handle the options switches

void Options()
{
	byte switchBytes[COLS];
	byte switch1;						// protocol (SW35 or SW37)
	byte switch2;						// brightness (SW36 OR SW38)
	
	// read the switch values
	
	digitalWrite(rowPins[4],LOW);
	for(int i=0;i<COLS;i++)
		switchBytes[i]=digitalRead(colPins[i])==LOW?1:0;
	digitalWrite(rowPins[4],HIGH);
	
	// decode the switch values
	
	switch1=switchBytes[2]+2*switchBytes[3]+4*switchBytes[4];
	switch2=switchBytes[7]+2*switchBytes[8]+4*switchBytes[9];
	
	// update options
	
	if(switch1<MAX_PROTOCOL)
		Protocol=switch1;
	else
		Protocol=DIAGNOSTIC;			// default protocol

	if(switch2!=Brightness)
	{
		Brightness=switch2;
		analogWrite(ledPin,BrightnessLevels[Brightness]);
	}
}

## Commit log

2017-11-08 Initial commit.
    [BaseUSBLeft.stl, BaseUSBRight.stl, Components.scad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]
2017-11-27 Update user manual. Update prototype photograph. Update key print files readme.
    [Stenokey_BOM.xls]
2020-02-25 Made minor changes to formatting and spelling and incidental changes to some text. Adjusted Dimension "InsertD2" in StenokeyCalse.scad to reduce possible upswelling around insert.
    [StenokeyCase.scad, Stenokey_BOM.xls]
2020-02-25 Updated Readme.md with an actual photo of Stenokey with the clamshell case.

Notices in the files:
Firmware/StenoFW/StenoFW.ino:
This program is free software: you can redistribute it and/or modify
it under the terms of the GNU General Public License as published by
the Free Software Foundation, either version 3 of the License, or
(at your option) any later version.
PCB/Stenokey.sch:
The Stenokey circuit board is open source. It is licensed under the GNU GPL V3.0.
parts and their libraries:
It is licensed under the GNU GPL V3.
